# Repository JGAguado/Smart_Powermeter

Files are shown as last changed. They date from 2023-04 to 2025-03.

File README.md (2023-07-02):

[][documentation]
[][releases]
[](LICENSE)

[][maintenance]
[][buymecoffee]

# Smart Powermeter
The Smart Powermeter is powered by a ESP32-S2, allowing the measurement up to 6 CT clamps for reading electric current and real-time display on an 2.9" e-paper display.

<p float="left">
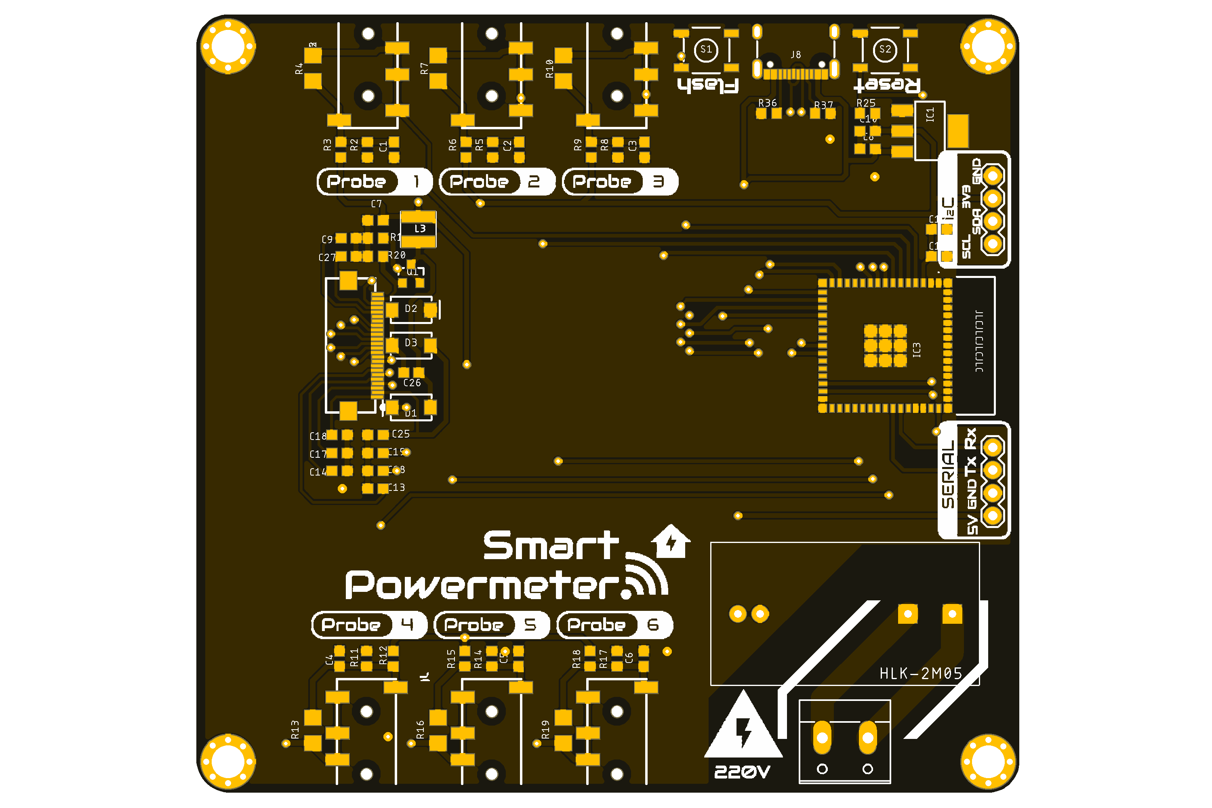
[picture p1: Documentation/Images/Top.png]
   
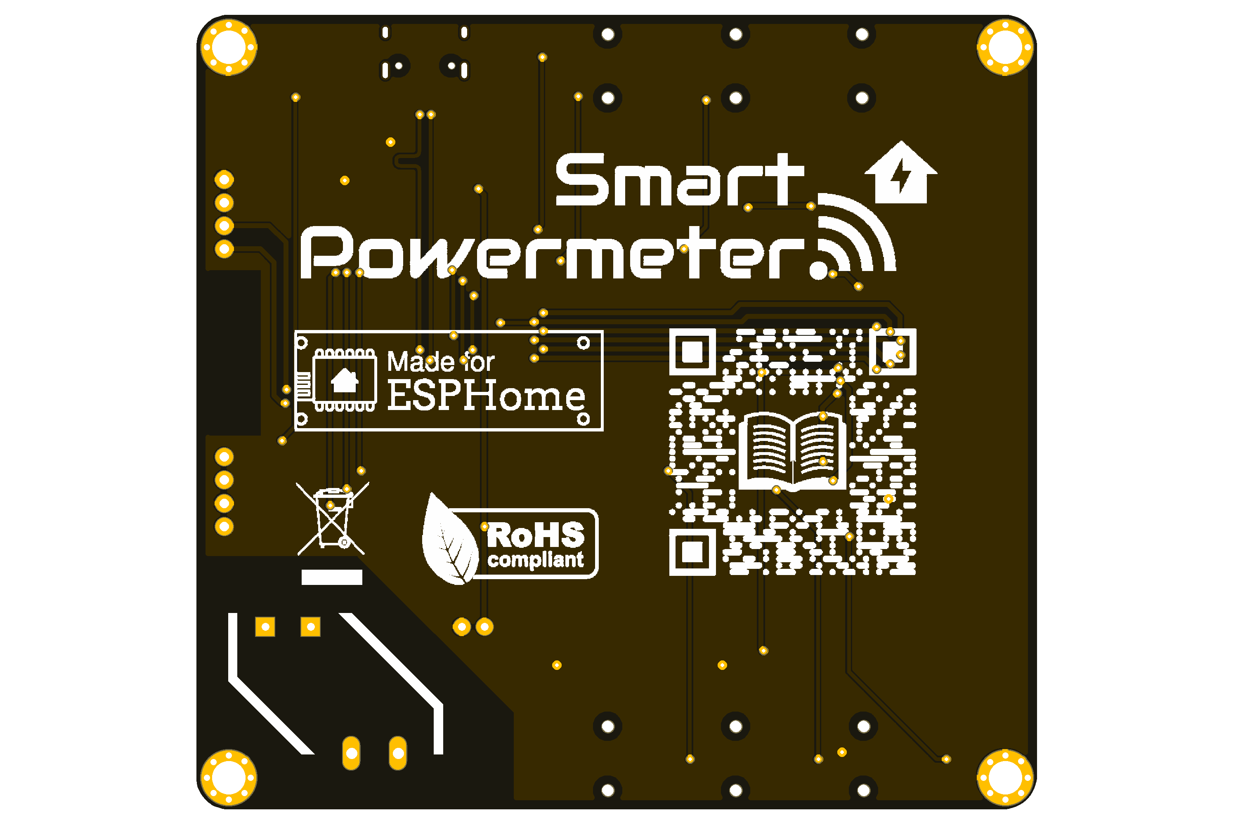
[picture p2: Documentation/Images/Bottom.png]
      
</p>

## Project tree

<li><a href="./Design/">Design</a></li>
<li><a href="./Documentation/">Documentation</a></li>

<li><a href="./README.md">README.md</a></li>

[documentation-shield]: https://readthedocs.org/projects/smart-powermeter/badge/?version=latest&style=for-the-badge
[documentation]: https://smart-powermeter.readthedocs.io/en/latest/

[releases-shield]: https://img.shields.io/github/release/JGAguado/Smart_Powermeter.svg?style=for-the-badge
[releases]: https://github.com/JGAguado/Smart_Powermeter/releases

[license-shield]: https://img.shields.io/badge/License-CC%20BY--NC--SA%204.0-lightgrey.svg?style=for-the-badge

[maintenance-shield]: https://img.shields.io/badge/maintainer-J.%20G.%20Aguado-blue.svg?style=for-the-badge
[maintenance]: https://github.com/JGAguado

[buymecoffee-shield]: https://img.shields.io/badge/buy%20me%20a%20coffee-support-yellow.svg?style=for-the-badge
[buymecoffee]: https://www.buymeacoffee.com/J.G.Aguado

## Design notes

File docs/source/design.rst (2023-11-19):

📐 Design
===========================

Electronic schematics
---------------------
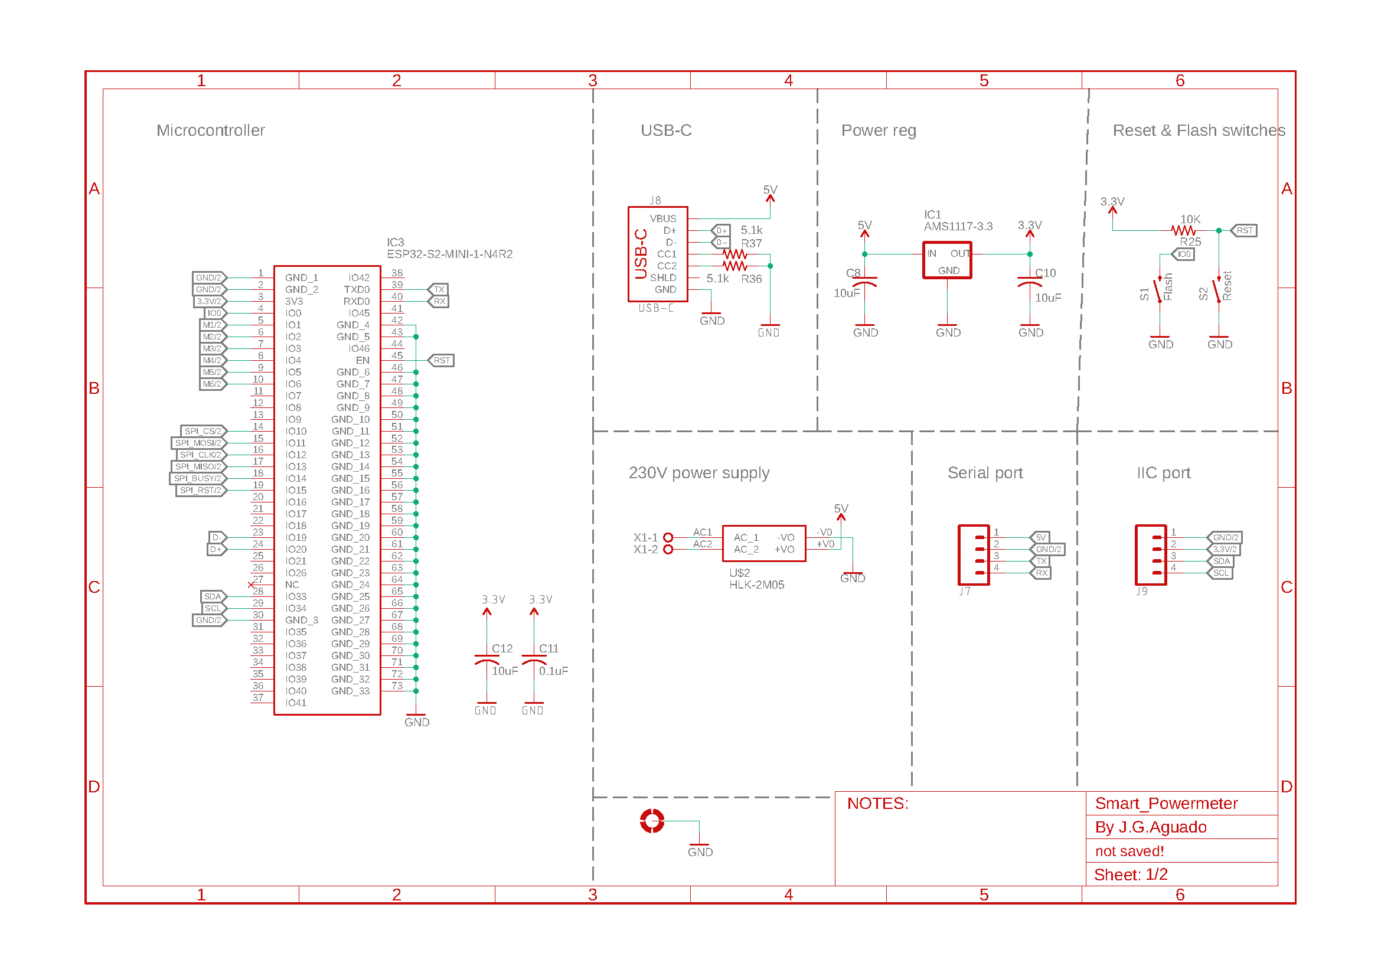
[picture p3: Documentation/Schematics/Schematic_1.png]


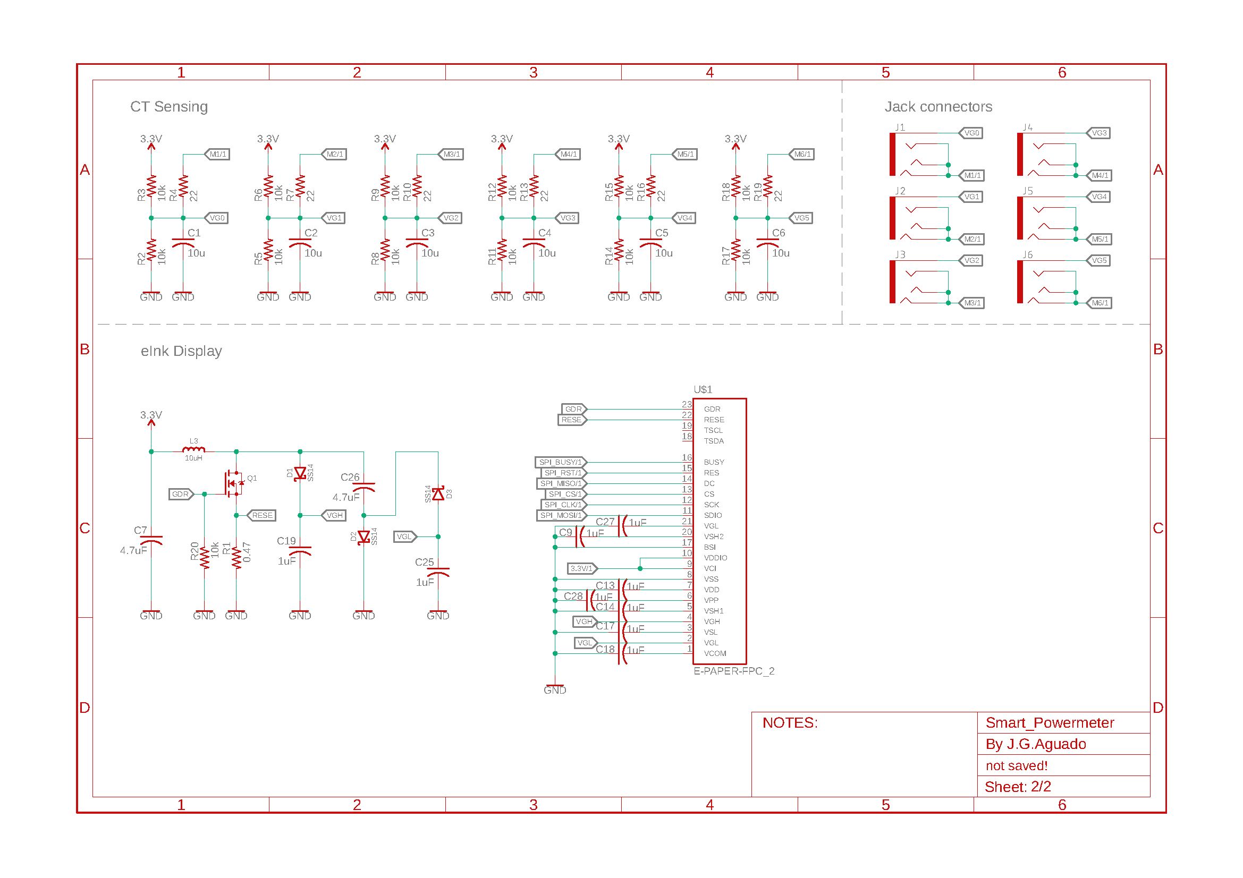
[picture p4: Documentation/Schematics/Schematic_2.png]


:download:`Download PDF <../../Documentation/Schematics/Schematic.pdf>`

.. _pcb:

:term:`PCB`
----------

.. raw:: html

    <iframe src="_static/ibom.html" height="800px" width="100%"></iframe>

Enclosure drawings
------------------

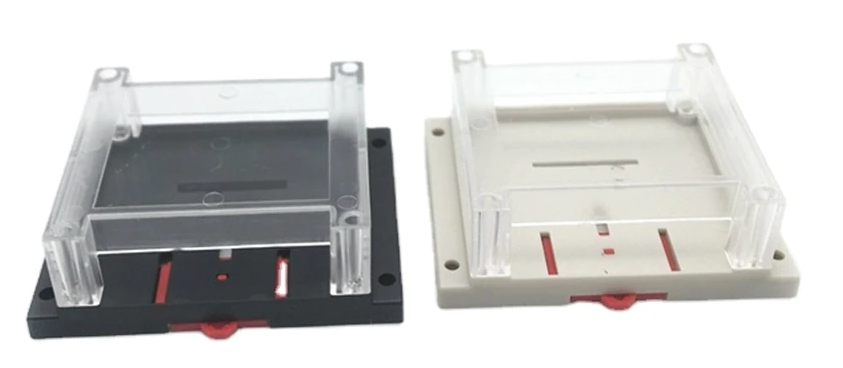
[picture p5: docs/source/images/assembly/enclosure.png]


:download:`Download PDF <../../Enclosure/LK-PLC01.pdf>`

Technical Specifications
------------------------

Microcontroller 
^^^^^^^^^^^^
.. list-table:: 
    :widths: 50 80
    :stub-columns: 1

    * - Module
      - ESP32-S2-MINI-1
    * - SoC
      - Xtensa® singlecore 32-bit LX7 up to 240MHz
    * - Flash
      - 4MB
    * - PSRAM
      - 2MB

Power
^^^^^^^^^^^^

.. list-table:: 
    :widths: 50 80
    :stub-columns: 1

    * - Input (AC) 
      - 100-240VAC | 50-60Hz
    * - Input (USB)
      - 5V @ 500mA

Features
^^^^^^^^^^^^

.. list-table:: 
    :widths: 50 80
    :stub-columns: 1

    * - Interface 
      - USB Type C 
    * - 
      - 2.4GHz WiFi 
    * - 
      - UART
    * - 
      - :term:`IIC` (:math:`I^2C`)
    * - Display
      - 2.9" e-paper 
    * - Sensors
      - 6x SCT-013-000 series CT-clamps

Dimensions
^^^^^^^^^^^^

.. list-table:: 
    :widths: 50 80
    :stub-columns: 1

    * - Size 
      - 92x87x20mm
    * - 
      - 115x90x40mm (with  enclosure)
    * - Weight
      - 60g
    * - 
      - 130g (with enclosure)

Environment
^^^^^^^^^^^^

.. list-table:: 
    :widths: 50 20 20 20 20 20
    :header-rows: 1
    :stub-columns: 1

    * - Parameter
      - Symbol
      - Min.
      - Typ.
      - Max.
      - Unit
    * - Working temperature [1]_
      - :math:`T_{amb}`
      - 0
      - 25 
      - 60
      - *°C*
    * - Storage temperature [1]_
      - :math:`T_{amb}`
      - 0
      - 25 
      - 60
      - *°C*

.. [1] Based on components datasheets.

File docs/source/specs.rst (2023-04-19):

Technical Specifications
========================

Electrical
----------

.. list-table:: 
    :widths: 50 20 20 20 20
    :header-rows: 1
    :stub-columns: 1

    * - Parameter
      - Symbol
      - Min.
      - Max.
      - Unit
    * - Supply voltage (AC)
      - :math:`V_{AC}`
      - 220
      - 240
      - *V*
    * - Power
      - *P*
      -  
      - 2
      - *W*

Environment
-----------

.. list-table:: 
    :widths: 50 20 20 20 20 20
    :header-rows: 1
    :stub-columns: 1

    * - Parameter
      - Symbol
      - Min.
      - Typ.
      - Max.
      - Unit
    * - Working temperature [1]_
      - :math:`T_{amb}`
      - 0
      - 25 
      - 60
      - *°C*
    * - Storage temperature [1]_
      - :math:`T_{amb}`
      - 0
      - 25 
      - 60
      - *°C*

.. [1] Based on components datasheets.

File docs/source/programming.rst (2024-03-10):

💻 Programming
===============

There are two main programming methods supported and tested with the |Product|: 

 * ESPHome
 * Arduino

In both scenarios, and if you are using the USB port or the Serial port for programming it, you
will first need to enter the board into flashing mode: press and hold the *Flash* pushbutton
while you reset the board (pressing once the *Reset* pushbutton).

.. Caution::
    When flashing the board, make sure its only powered by the USB/Serial port.
    
ESPHome
---------
`ESPHome <https://esphome.io>`_ is a well known platform for programming ESP-based devices 
with a very little effort. It is configured via YAML files and supports a wide range of functionalities
and sensors.

.. Important::
    For using ESPHome, and all its funcionalities, you need to have a `Home Assistant <https://www.home-assistant.io>`_ instance running
    in the same network as your |Product|.

The |Product| comes raw, without any firmware by default, therefore, you will need to flash it for first time. There are many ways to flash 
your ESPHome device (`locally <https://esphome.io/guides/getting_started_command_line.html>`_, `ESPHome Web <https://web.esphome.io>`_), but 
the one I strongly recommend is the one through the `ESPHome Add-on for Home Assistant <https://esphome.io/guides/getting_started_hassio.html>`_:

1. Make sure your ESPHome Add-on for HA is up to date and working. 
2. Add a new device, enter the name you want (like *Smart-Powermeter*), and skip the next step.
3. Select the *ESP32-S2* as the device type, skip the last step (installation). You will have created a provisional first configuration YAML file.

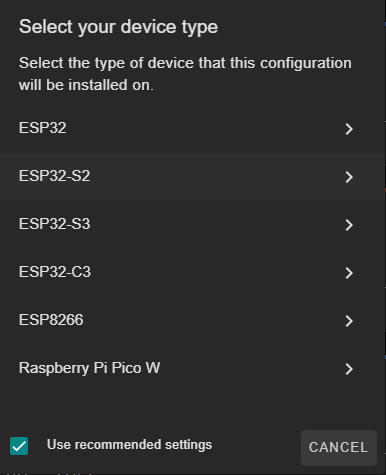
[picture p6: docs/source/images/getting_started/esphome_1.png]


4. Open the recently created file and replace the content with the example configuration. With all the dependencies, the working tree would look like:

.. Tip::
    A very easy way to upload and copy files (code or even images) into your ESPHome folder hosted in your HA instance is 
    with the help of the Visual Studio Code integration for HA. This way you can just drag and drop the files over the folder 
    on the Home Assistant’s Visual Studio Code navigation panel on your left.

| esphome
| ├── libraries
| │   └── icon-map.h
| ├── images
| │   └── Gauge.png
| │   └── Gauge_1.png
| └── smart-powermeter.yaml
| 
| 

In the folder structure above:
``icon-map.h`` 
    This *mapping* file is used to associate a variable name with the *icon ID* from the previous file. It contains the following code:
  
.. code-block:: C
   :linenos:

   #include <map>
   std::map<int, std::string> wifi_icon_map
   {
    {0, "\U0000f0b0"},
    {1, "\U0000ebe4"},
    {2, "\U0000ebd6"},
    {3, "\U0000ebe1"},
    {4, "\U0000e1d8"},
   };

``Gauge.png`` and ``Gauge.png``
    This are some customized gauges to be plotted as part of the background.

    
    

``smart-powermeter.yaml``
    This is the YAML configuration file, the most important file that configures your ESPHome-based |Porduct|:

.. Note:: You might need to keep the encription keys *OTA* and *API*

.. literalinclude:: files/configuration.yaml
   :language: yaml
   :linenos:

5. Click on install, make sure that the the board is connected via the USB-C (and that it is into flashing mode, see up in this guide) to the device running the Home Assistant (in my case a Raspberry Pi) before selecting the mode of installation.

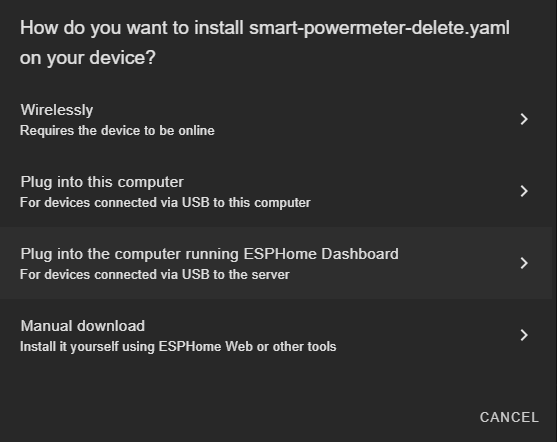
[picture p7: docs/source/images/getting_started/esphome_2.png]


6. Select the Serial port and let it run, it might take some minutes. 
7. Once it's done, you will have to exit the flashing mode: press the *Reset* pushbutton once. 

Now, your ESPHome-based |Product| should be ready to log data and stream it to your Home Assistant. Note that the current configuration is just an example and you can customize it at your will, including the calibration. 

Flash Tools
^^^^^^^^^^^^
If you want to deploy an ESPHome already compiled *.bin* image, you can use Espressif's official `Flash Download Tools <https://www.espressif.com/en/support/download/other-tools>`_ to upload it into your Smart Powermeter. 
As an example (and test) you can use this :download:`smart-powermeter-offline.bin <files/smart-powermeter-offline.bin>` image with the address `0x0`, make sure `DoNotChgBin` is checked:

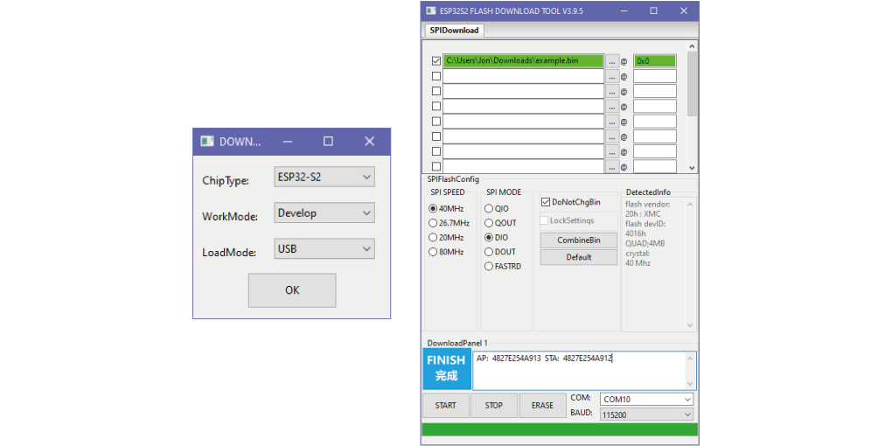
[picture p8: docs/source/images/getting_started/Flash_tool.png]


Arduino
--------
If you are still interested in programming directly with the Arduino IDE, the procedure is no 
different than with any other ESP32 devices:

1. Open the Arduino IDE and go to File -> Preferences option.
2. Add to the *Additional Boards Manager URSLs* the url:

.. parsed-literal::

    https://dl.espressif.com/dl/package_esp32_index.json

3. Close the preferences and open in the menu Tools -> Board -> Boards Manager.
4. Search for *esp32* and install it. This might take some time.
5. Now you can select the board *ESP32S2 Dev Module* as the target board. Leave the rest of parameters 
   by default.
6. Select the correct port and remember to enter the board into flashing mode before uploading the sketch.

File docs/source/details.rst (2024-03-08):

💡 Details
===============

Power
--------
The |Product| can be powered in two ways: through the USB-C (only for programming and testing purposes) **or** through the AC Input, but not simultaneously. 

AC Power
^^^^^^^^^^^^^
The `HLK-2M05 <https://www.hlktech.com/en/Goods-39.html>`_ module is a 2W AC-DC step-down 
switching power supply module, ready to receive 100-220V AC and deliver 5V DC that later on is reduced to 3.3V through an LDO (for the ESP32 module).

The board is designed to be powered directly through the screw terminal block. Before plugging the wires in, make sure they have no power.

Input
-----------
The |Product| supports up to 6 independent *analog inputs* ready to read CT clamps (or probes):

.. _pinout:

.. list-table:: Pinout table
    :widths: 10 20
    :header-rows: 1

    * - GPIO
      - Name
    * - 01
      - Probe 0
    * - 02
      - Probe 1
    * - 03
      - Probe 2
    * - 04
      - Probe 3
    * - 05
      - Probe 4
    * - 06
      - Probe 5

Regarding the kind of CT-clamps, I recommend the SCT-013 series, comming in a wide number of ranges and with a 3.5 jack connector:

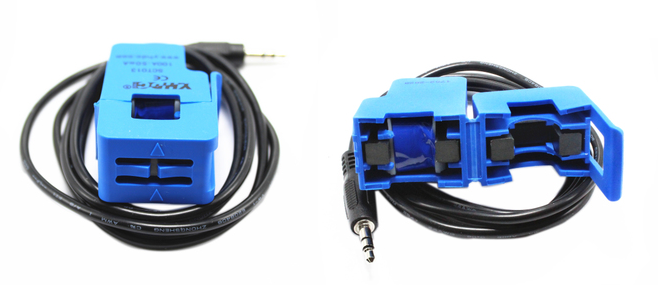
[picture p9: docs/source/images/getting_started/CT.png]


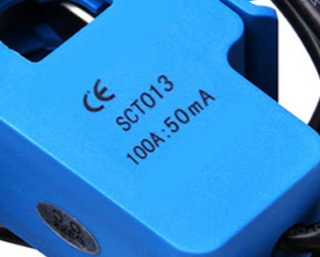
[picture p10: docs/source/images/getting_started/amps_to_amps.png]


.. list-table:: 
    :widths: 50 50
    :header-rows: 1

    * - Model
      - Ratio
    * - SCT-013-000
      - 100A:50mA
    * - SCT-013-005
      - 5A:1V
    * - SCT-013-010
      - 10A:1V
    * - SCT-013-015
      - 15A:1V
    * - SCT-013-020
      - 20A:1V
    * - SCT-013-025
      - 25A:1V
    * - SCT-013-030
      - 30A:1V
    * - SCT-013-050
      - 50A:1V
    * - SCT-013-060
      - 6A:1V
    * - SCT-013-000V
      - 100A:1V

When selecting a CT clamp, it is crucial to consider the anticipated measurement range. This ensures accurate measurements and prevents 
exceeding the ESP32's maximum reading range.

.. Note:: 
  The default CT clamp in the set is the SCT-013-000, which has the highest range in the series. However, for measurements al low power <10W, it may not provide the desired level of quality.

Each channel incorporates a simple internal circuit that adjusts the induced voltage from the CT clamp (proportional to the measured current) 
to prepare the signal for reading by the :term:`ADC` of the microcontroller. For more details on the circuit, refer to this 
`guide <https://docs.openenergymonitor.org/electricity-monitoring/ct-sensors/interface-with-arduino.html>`_.

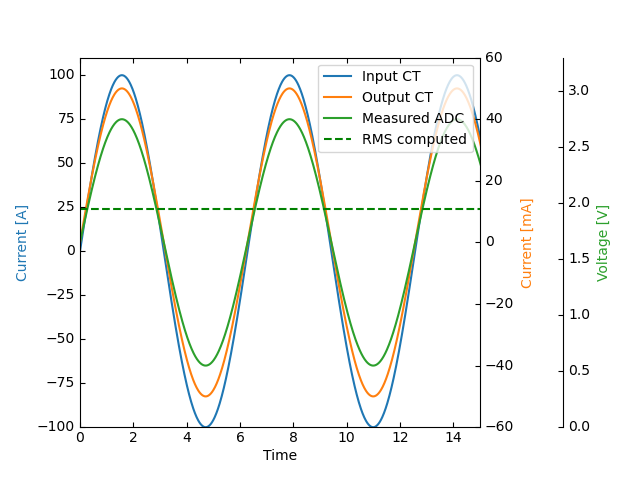
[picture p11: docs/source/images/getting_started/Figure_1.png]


In general, except for the SCT-013-000, the induced voltage can be read by the conditioning circuit mentioned earlier. 
However, if the CT clamp output is also a current, a burden resistor is necessary. The |Product| includes a **22 Ohm** resistor for 
convenience, making it easier to desolder if not needed, as explained in the :ref:`desoldering` section.

E-paper
--------
    
The |Product| offers support for a 2.9" black and white e-ink display, through a clamp connector. The pinout with respect to the ESP32 GPIOs goes as follows:

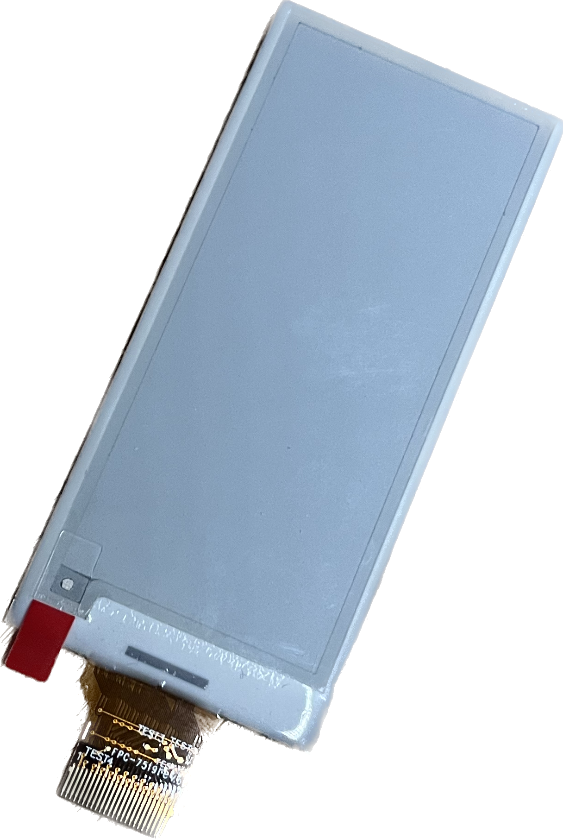
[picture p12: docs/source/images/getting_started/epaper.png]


.. list-table:: Pinout table
    :widths: 10 10 
    :header-rows: 1

    * - ESP32
      - E-paper
    * - 14
      - BUSY
    * - 15
      - RST
    * - 13
      - DC/MISO
    * - 12
      - CLK
    * - 11
      - MOSI
    * - 10
      - CS

Communications
-----------
In addition to the analog input mentioned before, there is also a direct connection to:

:term:`IIC` (:math:`I^2C`) bus:
^^^^^^^^
This port is not accessible from external pins, but internally connected to a BMP280 sensor that can offer info about 
environmental temperature & pressure:

:SDA: *GPIO33*
:SCL: *GPIO34*

Serial bus:
^^^^^^^^^^^
:Tx: *TXD0*
:Rx: *RXD0*

.. _enclosure:

Enclosure
---------
The |Product| has been designed to fit in the electronics enclosure LK-PLC01,
compatible with DIN rails and screws, and it is recommended for indoors only.



:External size: 115x90x40mm
:Material: ABS Plastic
:Color: Transparent cover, black or beige base

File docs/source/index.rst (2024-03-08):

Smart Powermeter
###############

.. raw:: html
        
    <iframe src="_static/carousel.html" style="width: 100%; height: 300px; border: none;"></iframe>

Welcome to the documentation page of the |Product|, an electronic board based on the ESP32 with 
the target of monitoring the real-time consumption of AC sources.

It can be powered from a :math:`220 V_{AC}` source so it can be mounted on the electric cabinet in order to monitor your home electric consumption.

In addition it can support 2.9" black and white e-paper display, in order to 
provide graphic information about the measured consumption, as well as spent money or any info you want to show.

Contents
--------

:doc:`safety`
    How to operate and manipulate the |Product|.

:doc:`details`
    A deeper explanation on the systems of the |Product|.

:doc:`getting_started`
    First steps for configuring and working with the |Product|.

:doc:`design`
    Design files of the |Product|.

.. _support:

Technical support
-----------------

If you have technical problems or cannot find the information that you need in the provided documentation, 
please contact me directly:

:Author: |Author|
:Contact: |Email|

:Board: |Product|
:Revision: |Release|
:Date: |Date|

.. toctree::
   :maxdepth: 3
   :hidden:

   safety   
   details
   getting_started
   design   
   glossary
   faq

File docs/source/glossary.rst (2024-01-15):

📚 Acronyms
============

.. glossary:: 
   :sorted:

   IC
       Integrated Circuit

   ADC
        Analog-to-digital converter

   TTL
       Transistor-Transistor Logic

   I/O
       Inputs / Outputs

   GND
       Ground

   OTA
       Over-the-Air

   PCB
       Printed Circuit Board

   PWM
       Pulse-width Modulation

   FF
       Flip Flop

   FAQ
       Frequently Answered Questions

   FPC
       Flexible Printed Circuit

   LDR
       Light Dependant Resistor

   LED
       Light Emitting Diode

   RGBW
       Red-Green-Blue-White

   NTC
       Negative Temperature Coefficient

   MDI
       Material Design Icons

   BOM
       Bill of Materials

   ESD
       Electrostatic Discharge

   SMD
       Surface-mounted device

   SMT
       Surface-mount Technology

   THT
       Through Hole Technology

   IIC
       Inter-Integrated Circuit

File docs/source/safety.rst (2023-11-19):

🦺 Safety guidelines
=================

These safety guidelines, the operation instructions and the limit values listed in :doc:`specs` are to be read carefully before operating the product.

.. Caution::
    This product has been designed for being used in domotic applications. 
    It was not designed for any use involving serious risks or hazards that could lead to death, injury, serious physical damage, or loss of any kind without the implementation of exceptionally stringent safety precautions.

Risk of electric shock
----------------------

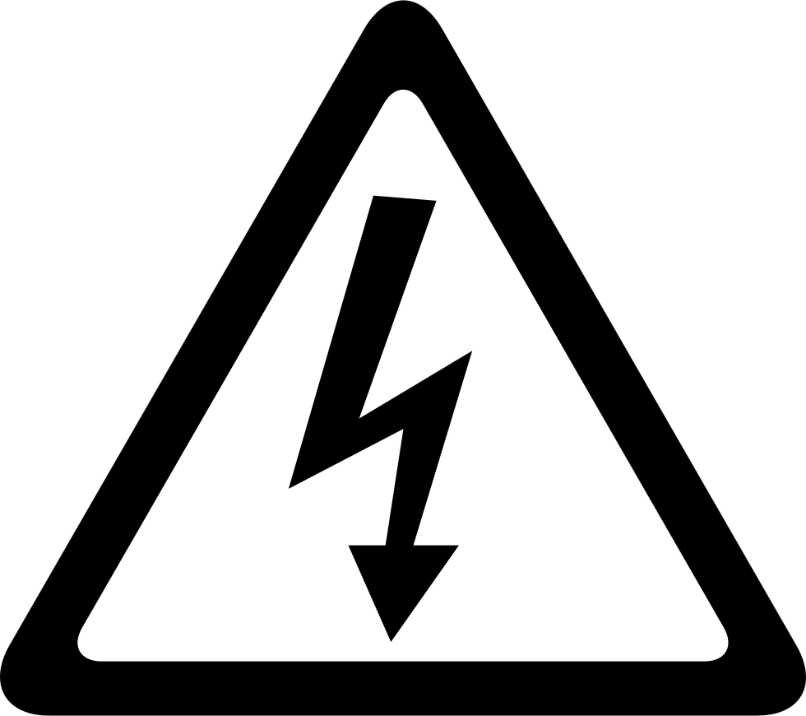
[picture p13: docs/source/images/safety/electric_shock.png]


The usage of this product could imply working with high voltage installations (:math:`220-240 V_{AC}`). Perform any action, specially in the area with this symbol on the board, with the appropriate means and always with safety. 

If you have any question, please check with technical support (:ref:`support`) before taking any action potentially dangerous.

Protection against :term:`ESD`
------------------------------

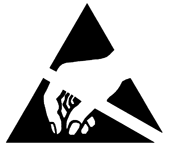
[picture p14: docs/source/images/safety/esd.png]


The |Product| contains components sensitive to :term:`ESD`, which can be damaged by inappropriate handling. 
It's therefore necessary to provide some safety precautions against :term:`ESD` during the handling and operation.

Usage, transport and storage
----------------------------

During the use, transport and storage, this product must be protected from any mechanical stress 
(forces applied over the board or it's components), temperatures out of the data-sheet's range, high 
environmental humidity or aggressive atmospheres.

Avoid using it in areas where it cannot be assured the previously mentioned environmental conditions.

Repairs
-------

If any of the components on the board gets damaged, a reparation is possible. This repair can be performed by 
yourself if you identify the problem and have the means for desoldering & soldering. If this is not the case,
just write to the :ref:`support` mail to reach a solution.

Disposal
--------

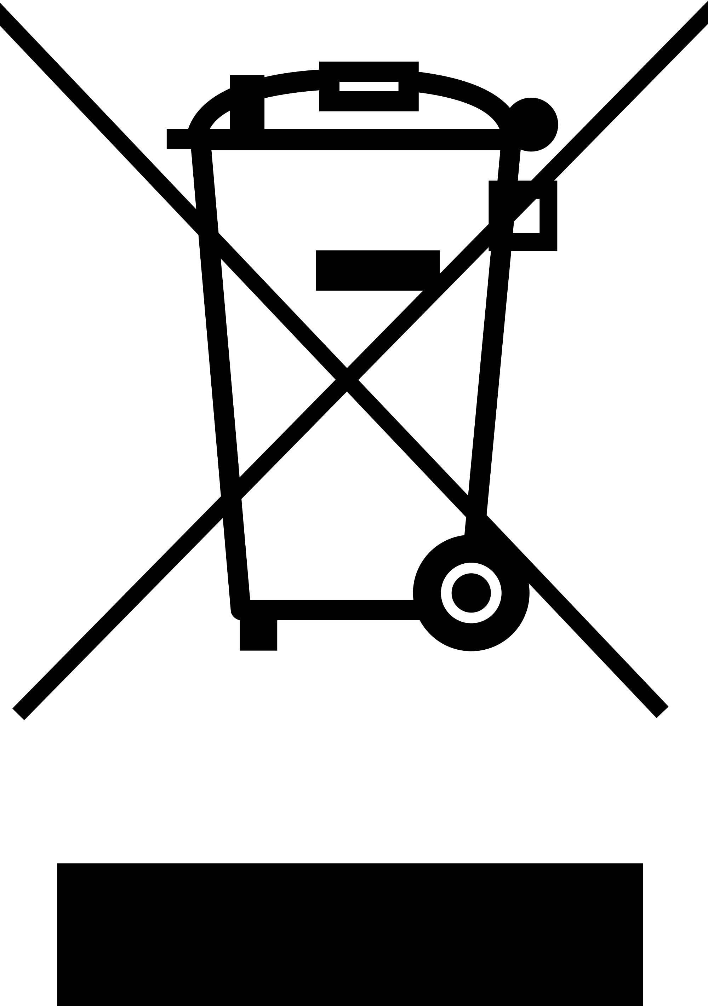
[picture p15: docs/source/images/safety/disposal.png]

    
In accordance with national and local environmental protection and material recovery and recycling regulations, 
electronic devices that can no longer be used (in case a repair is not possible) must be disposed of separately 
and not with normal household garbage.

Restriction of Hazardous Substances
-----------------------------------

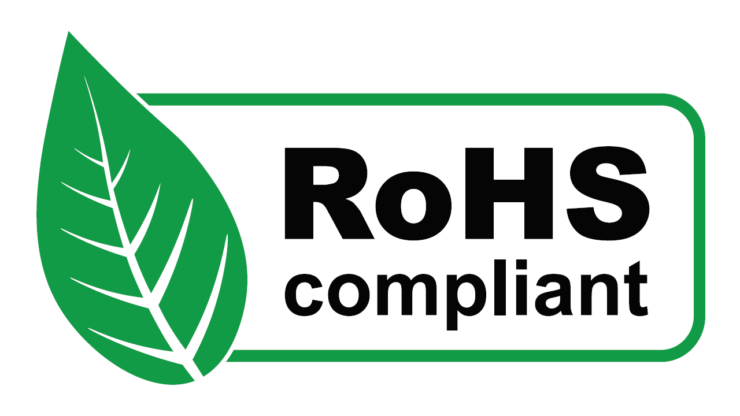
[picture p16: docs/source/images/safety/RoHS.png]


The :term:`PCB` and the electronic components mounted on the |Product| have been manufactured attending to the EU rules 
restricting the use of hazardous substances (RoHS) in electrical and electronic equipment to protect the 
environment and public health.

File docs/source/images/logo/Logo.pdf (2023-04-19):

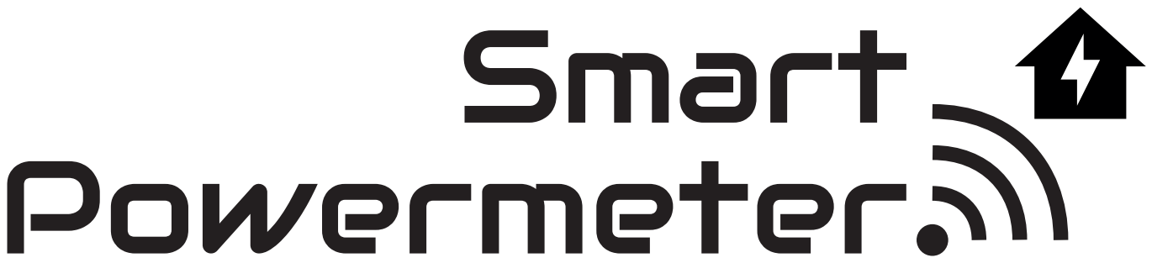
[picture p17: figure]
Smart Powermeter

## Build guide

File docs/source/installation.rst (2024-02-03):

🛠️ Installation
===============

Deployment
-----------

.. Danger::
    The installation of the Smart Powermeter should only be carried by people with **good knowledge about high-voltage electric installations** 
    and familiarized with the procedure that involves installing ct-clamps around main voltages.

After the board has been programmed physically, at least once, it should be ready to receive further updates :term:`OTA`. This means that 
the |Product| can be deployed and installed on it's final place, like an electric cabinet:

1. Locate an empty space on the DIN rail where you can install the enclosed |Product| and mount it.
2. Plug the CT-clamps into the |Product| through the jack connectors. 

.. Important::
    Don't introduce the jack connector completelly, leave ~1 millimeter, otherwise you might not see any signal.

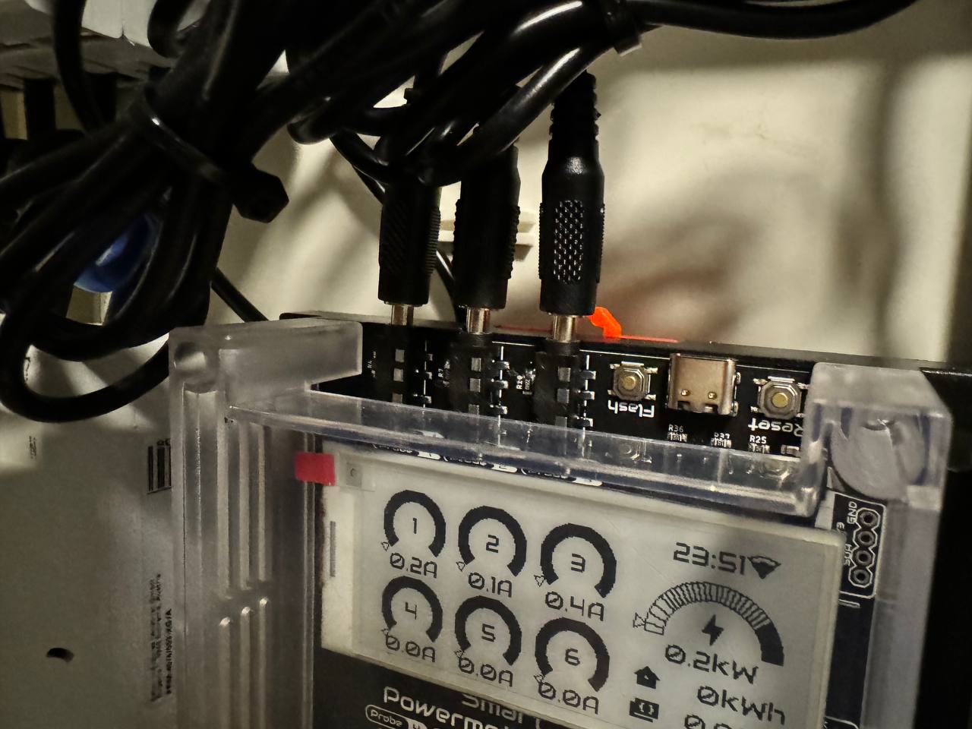
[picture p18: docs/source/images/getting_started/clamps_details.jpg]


3. Open the CT-clamps and close them around the power line you want to measure.

.. Caution:: 
  High-voltage cables are very rigid and using too much force for helping claping the instrument 
  around the cables may disconnect them.  

4. Power the |Product| out of any surrounding power lines. **Before connecting anything make sure it is not powered**.

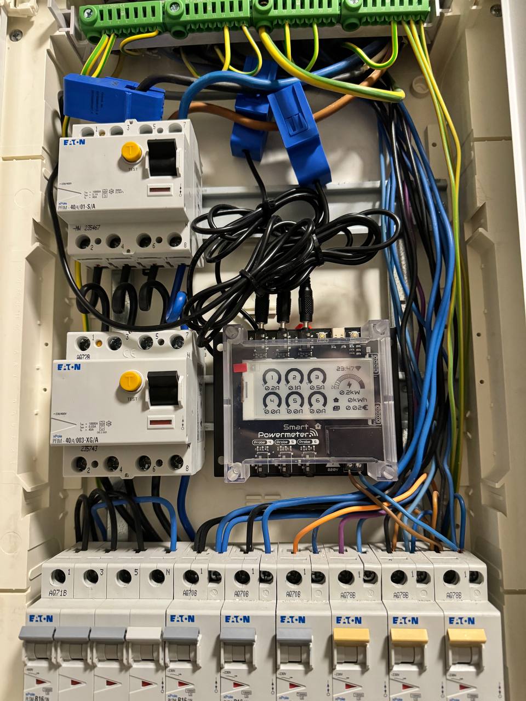
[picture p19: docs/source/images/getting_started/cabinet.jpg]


Calibration
------------

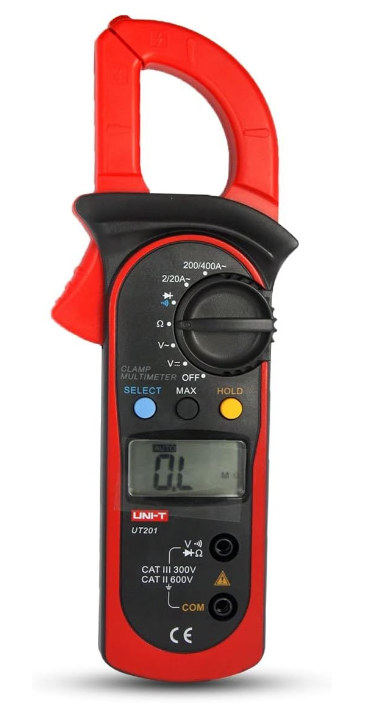
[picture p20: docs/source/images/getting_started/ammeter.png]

    
Although the theoretical value calculated should be good enough for the measurements, I strongly recommend to calibrate each channel with an external handheld ammeter:

In general lines, calibration procedure consists on the basic points:

1. Instrument with an external ammeter the same power line you are measuring with your CT-clamp.
2. Measure at multiple currents, for that turn on different loads consumming differently.

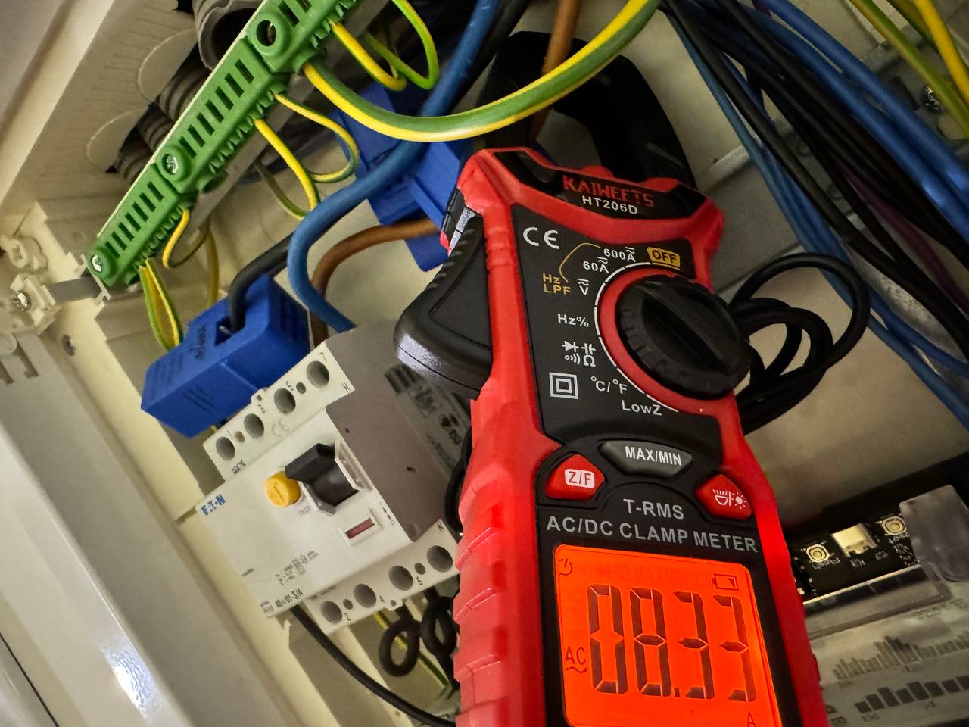
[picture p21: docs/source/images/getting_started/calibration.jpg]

    
3. Apply the coefficients. On ESPHome this is done by entering the multiple measurement points into a filter *calibrate_linear*, like this:

.. parsed-literal::

    filters:
      - calibrate_linear:
          - 0 -> 0
          - 0.042 -> 2.72 # Where 0.042 was the reading from the ESPHome and 2.72 the amps measured with the calibrated instrument

4. Verify that the calibrated measurement matches with what the ammeter displays. Test different loads again.

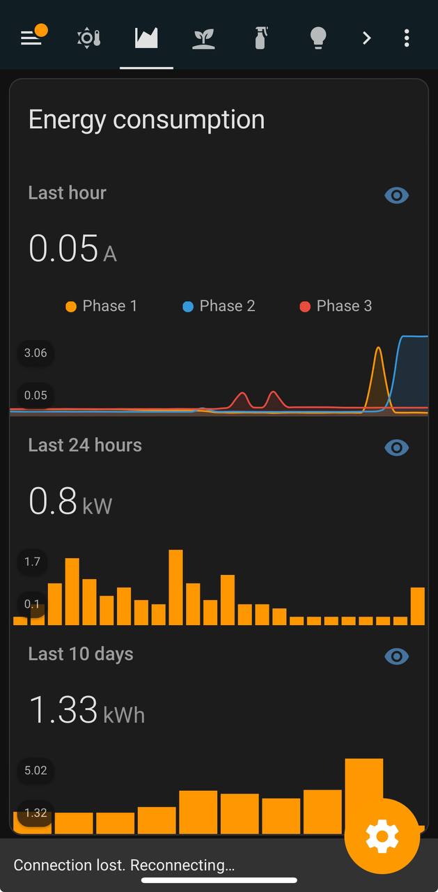
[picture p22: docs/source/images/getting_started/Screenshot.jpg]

    
    HA App screencapture of testing loads on the different phases.

Home Assistant setup
--------------------

After the device is installed and calibrated, make sure you add the computed power parameter as part of the grid consumption.

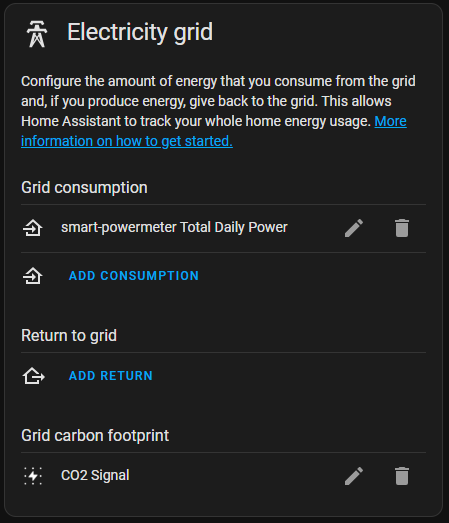
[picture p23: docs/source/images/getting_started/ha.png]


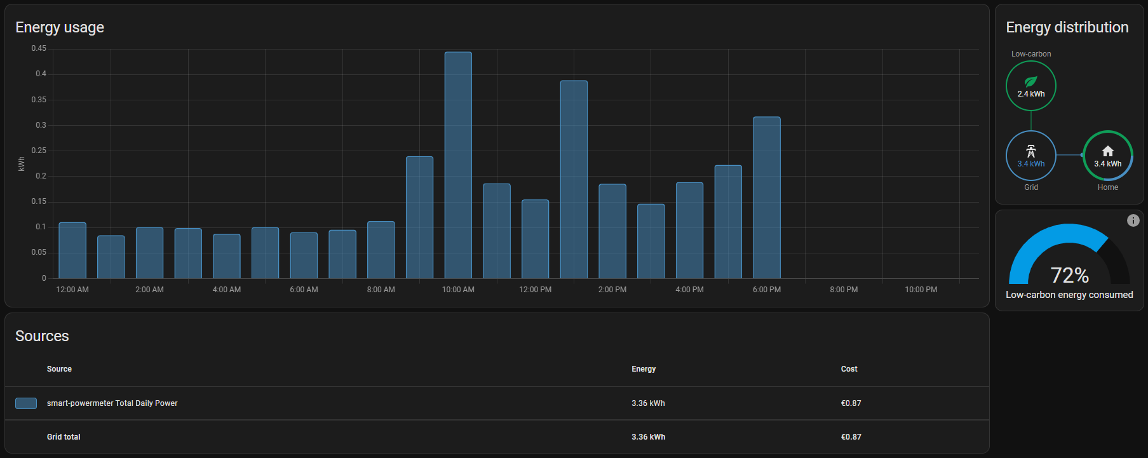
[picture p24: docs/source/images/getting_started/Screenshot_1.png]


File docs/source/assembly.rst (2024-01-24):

🏗️ Assembly
============================

Soldering 
----------
.. Important::
    Please note that some components in this board need to be soldered.

The |Product| comes as a set consisting on a :term:`SMD` pre-soldered board to which you will need to mount the following components:

* `HLK-2M05 <https://www.hlktech.com/en/Goods-39.html>`_ power module, a 2W AC-DC step-down switching power supply module :term:`THT` solderable.
* A 2-Pin 2mm-pitch screw terminal block, for the AC power imput, also :term:`THT` solderable.

.. Note:: 
  When buying the |Product| read the product description to make sure these two components are included, otherwise you might need to get them on your
  own.

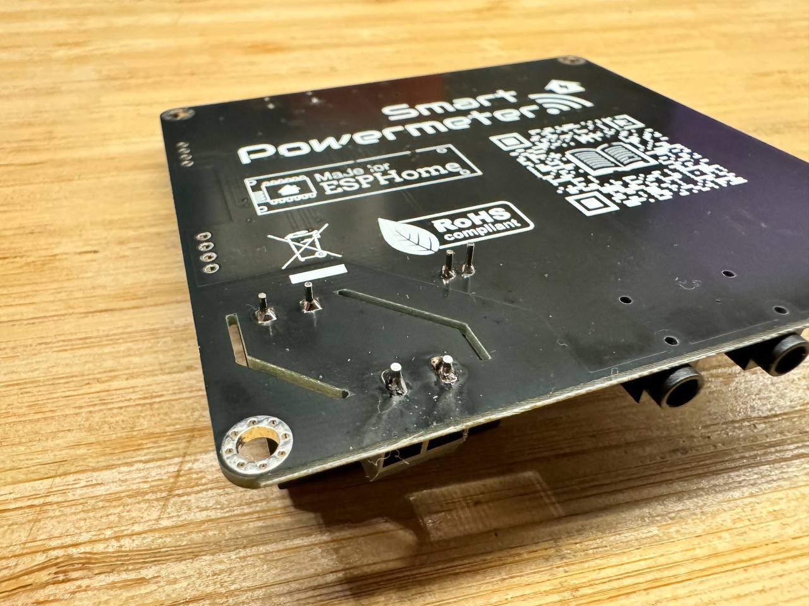
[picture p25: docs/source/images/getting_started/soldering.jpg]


The soldering of these two components is quite fast, just make sure not to bend any of the power supply module pins. If you have never soldered or you want to improve your soldering techniques I recommend you 
the `Adafruit Guide To Excellent Soldering <https://learn.adafruit.com/adafruit-guide-excellent-soldering>`_

.. _desoldering:

Desoldering
------------
If you ever need to desolder any burdern resistor, for instance, when opting for a different CT clamp on that channel, simply apply heat and remove it carefully.

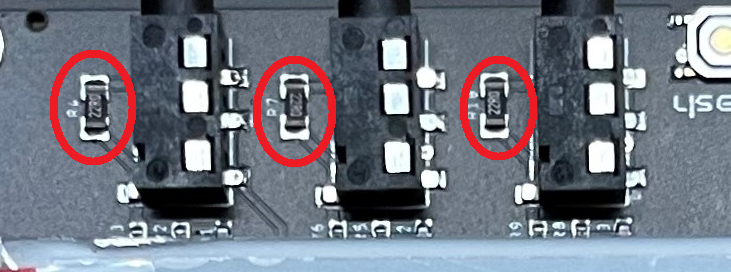
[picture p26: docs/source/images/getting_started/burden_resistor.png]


Assembly
--------
Once the board is fully soldered, it's time to mount the e-paper display (in case you are using this accessory to display real-time information):

1. Open the clamp connector, by smoothly pulling up the tab.
2. Introduce the e-paper :term:`FPC` with the exposed pads facing down (against the PCB)
3. Close the clamp connector
4. Bend carefully the e-paper's :term:`FPC` in a way that the panel rests over the PCB. Add a very small piece of double-side tape on the rear to fix it.

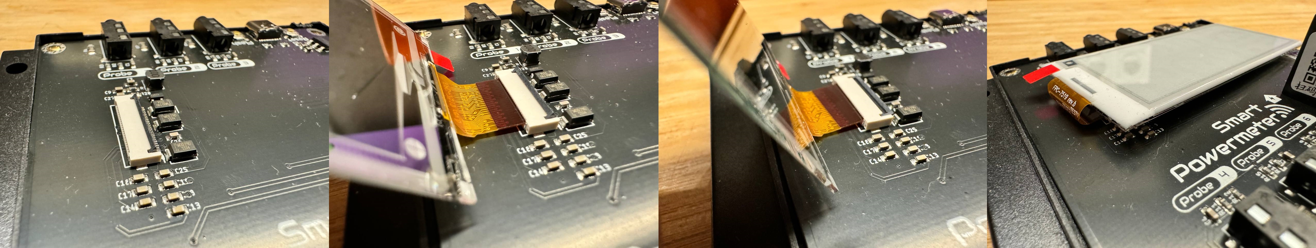
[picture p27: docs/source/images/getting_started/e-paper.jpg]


Last but not least, it is highly recommended to mount the |Product| on an enclosure (like the suggested :ref:`enclosure`) to prevent unintended contacts between the bottom 
side of the board (since the hig-voltage pins are exposed).

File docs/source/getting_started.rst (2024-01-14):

🚀 Getting started
===============
  
    Trust me, I know what I'm doing...

    -- Every engineer while ignoring the instructions book.

Regardless of your professional background, I encourage you to have a quick read through the following pages in order to get your |Product| 
onboarding smoother and minimize the risk of damaging the device and/or yourself.

.. toctree::
   :maxdepth: 2

   assembly
   programming
   installation

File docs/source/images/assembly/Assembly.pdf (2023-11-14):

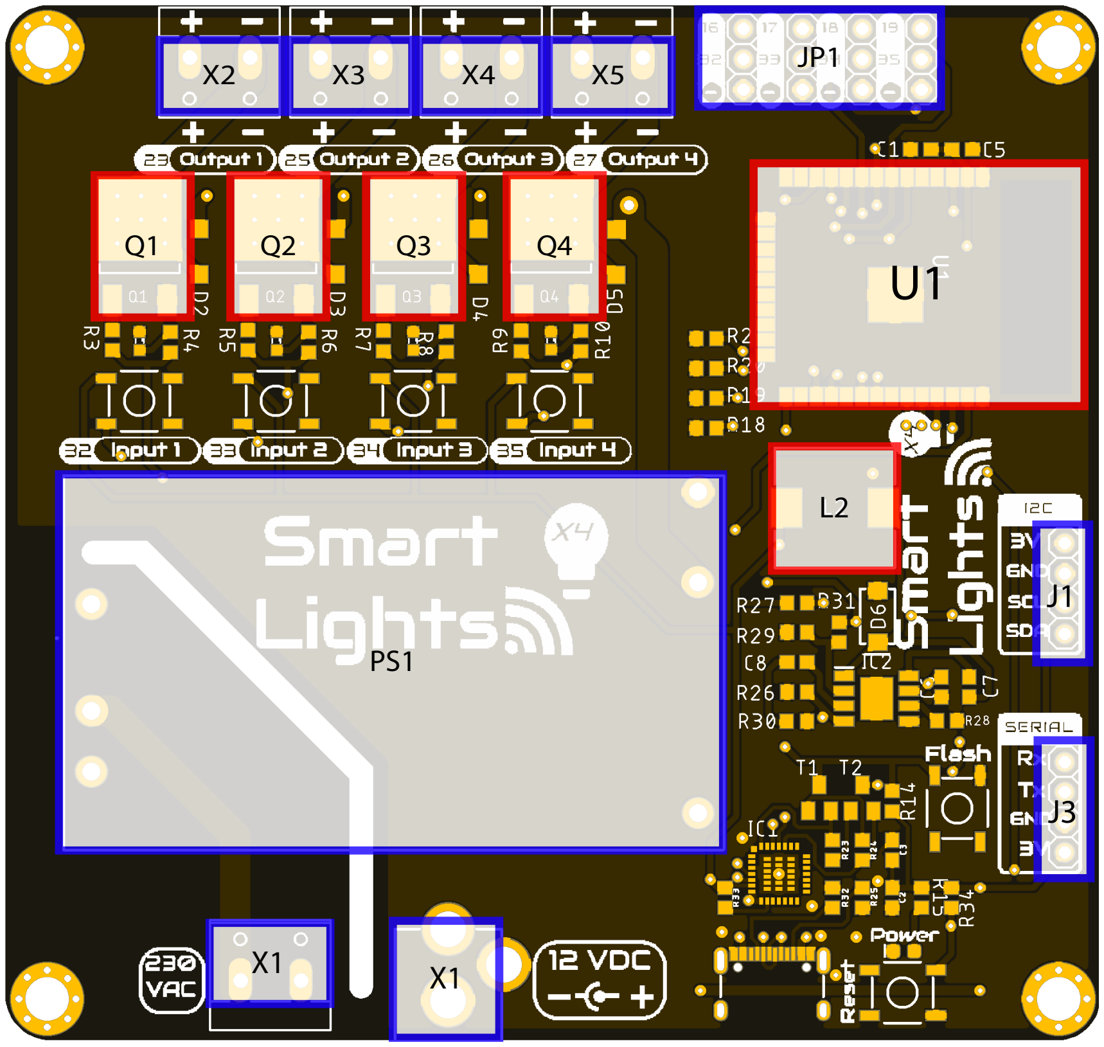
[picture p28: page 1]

Q1
U1
Q2 | Q3 | Q4

X2

X1 | X1

J1

J3

JP1

PS1

X3 | X4 | X5

L2

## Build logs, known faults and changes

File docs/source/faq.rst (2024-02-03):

💬 :term:`FAQ`
=============================

The readings from the CT clamps are very noisy and I don't see any signal at all
    Most likely is because the jack connectors from the CT clamp are too deeply inserted: try pulling them out about ~1-2 mm from the point where they would bottom out.  

Can I upload ESPHome directly from the Home Assistance setup running on my Raspberry Pi?
    Yes you can, and actually this is one of the simplest and more effective way to upload ESPHome.

Can I upload firmware through the USB-C?
    Yes, the ESP32-S2 includes a full-speed USB On-The-Go (OTG) interface to enable USB communication.

Can I upload firmware through the Serial bus?
    Yes you can, however this is only recommended if you have troubles using the USB port and you are familiar with the procedure.

I have CT clamps that gives me the output in voltage instead of current (100A:1V), is it still compatible?
    Yes, you just have to desolder the burden resistor close to the connector of the channel you want to use. 

Am I obtaining the accurate measure of power consumption?
    Strictly speaking, no; what you're obtaining is the **apparent** power. The real or true power of a circuit considers the phase (power factor). 
    As we are solely monitoring the current and assuming a constant voltage, we cannot factor in the phase shift between voltage and current. 
    Consequently, what we can calculate is the apparent power. Nevertheless, unless you have robust inductive loads at home, such as powerful motors, 
    the power factor tends to be close to unity, resulting in a very close alignment between the measurement of apparent power and real power.
    If you want to understand more about the differences between True, Apparent and Reactive power have a look at this `article <https://www.allaboutcircuits.com/textbook/alternating-current/chpt-11/true-reactive-and-apparent-power/>`_ 

I want to use the :term:`IIC` port for expanding the possibilities, how can I do it?
    Once you have located the sensor that you want to connect to the :term:`IIC` port, check that is compatible with the 3.3V power supply from the |Product|. 
    If this is the case, just connect it directly, power the board and update the firmware!

When I try to compile the given YAML and upload it into the board I get some error messages saying that I miss some files (Audiowide.ttf, icon-map.h, etc). How to fix it?
    Just the configuration YAML file isn’t enough and you might get an error asking for missing items (the fonts and the images). The reason is because
    on the configuration we are asking for some files (the fonts that you want for the digits or the icons and the background image with the gauge, for example).
    
    Therefore you need to upload into the folder with the configuration YAML file the required files. I strongly suggest to use Visual studio code and just drag and 
    drop the items according to the structure mentioned on the :ref:`esphome` programming section.

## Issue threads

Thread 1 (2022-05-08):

Power transformer on the left

JGAguado, 2022-05-08:
So it doesn't block the USB-C port

JGAguado, 2023-07-05:
c3e27f7b080b054ba54b7329635745d98501c130

Closed 2023-07-05.

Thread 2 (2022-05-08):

Silkscreen bug

JGAguado, 2022-05-08:
Start in Input_0 and missing input_4

JGAguado, 2023-07-05:
c3e27f7b080b054ba54b7329635745d98501c130

Closed 2023-07-05.

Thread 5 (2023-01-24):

ESP32-S module based

JGAguado, 2023-01-24:
- Board design based on the smart-lights /smart-garden platforms
- E-ink based (2.9 inches)

JGAguado, 2023-07-05:
c3e27f7b080b054ba54b7329635745d98501c130

Closed 2023-07-05.

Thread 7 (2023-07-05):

Production files

CountParadox, 2023-07-05:
Hi OP

Thanks for the hard work, your board looks amazing :)

Would it be possible to get some production files eg. gerbers, drill, bom, placement etc to get some board s manufactured at JLCPCB or PCBway for example ?

Your store is out of stock and theres no clues when they may be back :(

Myself and a few friends would love to get a few boards

I would appreciate any help !

Thank you

JGAguado, 2023-07-05:
Hi Lewis,

Thanks for your interest and support! Normally I don't upload the production files, but the design ones, so you can freely generate your production file.

Since I am still testing the V2R1, I haven't tagged a release, I hope to validate the functionalities this next week and update the documentation, but the design files already available wouldn't change.

If you are more interested in acquiring some semi-assembled units (I have some prototypes V1R1 and V1R2), send me an email to jon-garcia@hotmail.com

Closed 2023-07-05.

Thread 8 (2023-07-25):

No voltage measurement

agkaminski, 2023-07-25:
Please take a note that you cannot accurately measure AC power by only measuring current. Without information about phase shift between the voltage and the current you cannot measure real power usage - you can only measure apparent power, which is kinda useless.

Wikipedia has it laid out accurately enough: https://en.wikipedia.org/wiki/AC_power

JGAguado, 2023-07-25:
The current board provides a real-time **estimation**. Voltage measurement is a feature that will come in future versions.

agkaminski, 2023-07-25:
You seem to misunderstand the issue - amplitude of the voltage is not really needed (as we can assume 230V and live with it), but the phase is necessary

JGAguado, 2023-07-25:
Dear Aleksander, I understand perfectly the issue. If you dig a little bit into the firmware my board is compatible with (ESPHome), you will find that the power factor computation is not supported a the moment. Since I don't take part in the firmware development, it made no sense for me to implement (at least in the first versions) the voltage measurement for computing the phase offset, true and reactive power.

Saentist, 2025-03-31:
@JGAguado
Voltage can be taken from Home assistant
https://esphome.io/components/sensor/homeassistant.html

That's how, if any device report it already can be used.
Documentation and config file update needed also.

Closed 2023-07-25.

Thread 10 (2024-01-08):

BOM and CPL Files Available?

mdframe, 2024-01-08:
Does anyone have all the files necessary to order the PCB from JLCPCB for board and components for R2?

Thank you,

Matt

mdframe, 2024-01-08:
Is there any way to get notified when the next batch is ready for an order?  I appreciate the quick response and yes all I am looking to do is place an order.

Thank you,

Matt

JGAguado, 2024-01-08:
Let me come back to you on this channel when it becomes available.

JGAguado, 2024-01-09:
Dear @mdframe,

You are very welcome! Would be great to have you supporting the Smart Powermeter's features on ESPHome! And yes, please keep me posted on any updates you make!

At the moment, the published code, is focused on the measurement, and a "Hello World" test for the display. So if you would make any advance with some cool graphs or so, please keep me posted 😃 !!

The problem with the code running behind the Smart Powermeter shown in the photos, is that it required a Python script running in Home Assistant to convert the gathered power data from ESPHome into a scaled array (x,y,w,h), that I later passed back to the ESPHome to be plotted. Unfortunately, on one of the last HA updates, it stopped working and I need to find some time to fix it... Since it broke, I am just plotting the measured data with the standard points, which is not that nice, but does the job...

I will close this issue now, but for further questions don't hesitate to write me by email (jon.garcia.aguado@gmail.com) or IG (@JGAguado), I may answer faster.

Best regards and thanks for the support!

Jon

Closed 2024-01-09.

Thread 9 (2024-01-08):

ADC measurement resolution

jibrilsharafi, 2024-01-08:
Hi,

I see that the board has no external ADC or energy metering IC, which means all the (current) waveform sampling will be done on the ESP32. Isn't this non-recommended since the ADC has a lot of noise, especially in the mV region (which translates into 100s of mA and 10s of W)?

Have you taken this into account in your board design?

JGAguado, 2024-01-08:
Hi @jibrilsharafi ,

Yes, you are right, The reading is done through the internal ESP32's ADC.

This doesn't necessarily mean that has a lot of noise, since it has a 12-bit resolution and the RMS can be read in a range of 1.65V, we get a resolution of 0.402mV. Depending on the CT clamp ratio you choose, you will be able to read the current with more or less quality.
On the other hand, by using ESPHome, the [CT Clamp component](https://esphome.io/components/sensor/ct_clamp.html) computes the RMS directly, so this helps filtering undesired noise (I think around 900 samples/second).
I'm aware it's not a completely noise-proof design, but so far does a good job at a reasonable cost: for monitoring, in a non-invasive way, my home's apparent power is more than enough.

Best regards!

Closed 2024-01-08.

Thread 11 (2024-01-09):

Suitable for 3 phase?

eina84, 2024-01-09:
I just purchased one of your units on Elecrow today to replace my Neurio unit which is no longer supported & appears to have stopped working.
Is the Smart Powermeter suitable for 3 phase? My condo uses 3 phase.
Also, I ordered the pack with 6 CT Clamps - can I use 3 of them to measure the 3 phase input & then the other 3 to maybe measure specific current draws of 3 big items like my air conditioners?
(sorry if this isn't the right place to ask - I couldn't find another site with discussion area)

JGAguado, 2024-01-09:
Dear @eina84,

Yes, my apartment also uses triphasic. I am monitoring each one of the phases and so far works fine for me, and yes, with the other 3 clamps you should have no problems monitoring other current lines.
By monitoring each of the phases I compute on ESPHome the total apparent power this way:

```
 - platform: template
    id: current_power
    name: "Measured Power"
    lambda: return (id(Probe_1).state + id(Probe_2).state + id(Probe_3).state) * 230.0 / 1000; #Apparent power = Current * Voltage
    unit_of_measurement: 'kW'
    update_interval: 5s
```

This is a pic of the first version of the Smart Powermeter, but the concept is the same:
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

I will close this issue now, but for further questions don't hesitate to write me by email ([jon.garcia.aguado@gmail.com](mailto:jon.garcia.aguado@gmail.com)) or IG ([@JGAguado](https://www.instagram.com/JGaguado/)), I may answer faster.

Best regards and thanks for the support!

Jon

Closed 2024-01-09.

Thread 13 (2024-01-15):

Documentation - Assembly - Typo

mdframe, 2024-01-15:
Jon,

I found a typo in the documentation detailing the ESPHome folder structure:

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

I am working through your code to verify what is working from a user stand point.  I am also having a really difficult time finding the correct webfont file and believe this is causing me errors with the  following line:

 it.printf(x_head, y_head, id(font_icon), TextAlign::TOP_LEFT, wifi_icon_map[4].c_str());

ESPHome compiler is stating no wifi_icon_map exists, here is the error:

<unicode string>: In lambda function:
<unicode string>:269:71: error: 'wifi_icon_map' was not declared in this scope
<unicode string>:269:71: note: suggested alternative: 'wifisignal'
<unicode string>:272:71: error: 'wifi_icon_map' was not declared in this scope
<unicode string>:272:71: note: suggested alternative: 'wifisignal'
<unicode string>:275:71: error: 'wifi_icon_map' was not declared in this scope
<unicode string>:275:71: note: suggested alternative: 'wifisignal'
<unicode string>:278:71: error: 'wifi_icon_map' was not declared in this scope
<unicode string>:278:71: note: suggested alternative: 'wifisignal'
<unicode string>:281:71: error: 'wifi_icon_map' was not declared in this scope
<unicode string>:281:71: note: suggested alternative: 'wifisignal'

Again, I think this is related to the ttf file I am trying to use since I can't find the defined one in the code.  This is the only item I have an error on at this point.   Just working through the YAML prior to receiving the hardware.  I will make sure this works locally before making recommendations or changing your code as it sits right now.

Thank you,

Matt

JGAguado, 2024-01-15:
Matt,

Thanks a lot for opening the issue, it makes me really happy that at least someone read the docs hahaha. The tree typo has been corrected and I added a downloadable MDI .ttf like the one I use.

Can I close the issue or there is something else not compiling?

Best regards!

Jon

mdframe, 2024-01-15:
Thanks Jon, I'm good at this point until I get hardware in hand!  ;)

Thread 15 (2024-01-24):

New Device is DOA

mdframe, 2024-01-24:
Jean,

I received my new device today, added the power connectors and the E-Paper per instructions.  I DID NOT apply any external power.  Only using 5 different USB-C cords and two different computers I get nothing.  No connection no sign of life.  What can I check on this board for valid power and connection with the USB-C?

Thanks,

Matt

Brockhold, 2024-01-24:
Hey, I actually thought the same thing happened to me today, [but it turns out I didn't read the manual](https://smart-powermeter.readthedocs.io/en/latest/programming.html) - to show up as a USB serial device for loading firmware, after connecting the USB cable you have to hold down the FLASH button and then press the RESET button.

mdframe, 2024-01-24:
Ben,

Thank you, I've read this document several times and not sure how I missed that!  I will try this one I get home.

Appreciate the help!

Matt

JGAguado, 2024-01-24:
Thanks for answering @Brockhold ! Since it is a recurrent issue, I will emphasize it on the [FAQs](https://smart-powermeter.readthedocs.io/en/latest/faq.html)

I will close now the topic, feel free to reopen it if it didn't work!

Best regards!

Jon

Closed 2024-01-24.

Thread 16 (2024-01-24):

Measurements with `SCT-013-000` and the built-in 22R resistor seem close to identical

roobre, 2024-01-24:
Hi there!

Yesterday I finished assembling my smart power meter but I'm struggling to get it to measure reliably. Trying to go through the calibration step, the device does not seem to be able to discern no current (0A) from 2.1A as measured by an external ammeter (which also matches the expected draw for the load I connected).

The YAML I'm using is as follows:
```
sensor:
  - platform: adc
    pin: GPIO1
    id: Input_1
    attenuation: 11db
    update_interval: 1s
# ...
  - platform: ct_clamp
    name: Probe 1
    id: Probe_1
    sensor: Input_1
    sample_duration: 200ms
    update_interval: 1s
    # filters:
    #   - calibrate_linear:
    #       - 0 -> 0
    #       - 0.042 -> 2.72
# ...
```

Notice the filter section is commented out for calibration. Looking at the logs for lines like:

```
[22:55:16][D][sensor:094]: 'Probe 1': Sending state 0.00176 A with 2 decimals of accuracy
```

I collected ~20 of those lines for a 0A and a 2.1A load and crunched some numbers on a spreadsheet. From that, I got that:
- A 0A load reported an average of `0.001685` with an standard deviation of `0.00028`
- A 2.1A load reported an average of `0.001727` with an standard deviation of `0.00026`

What I understand from these numbers is that measurements of 0W (0A) and ~500W (~2A) are within standard deviation from one another, making them hardly distinguishable.

I wonder if this is expected, or if I'm doing something wrong. I'm fine hacking the meter and replacing the 22R resistors with something higher, but I would like to double-check with you to see if what I'm seeing is the expected behavior, or if on the contrary I'm doing something wrong.

[measurements.ods](https://github.com/JGAguado/Smart_Powermeter/files/14037611/measurements.ods)

roobre, 2024-01-24:
Figured this out. The adc was reading noise because, at least on my unit, it doesn't seem like you should plug the jacks all the way into the receptacles. If you do (like I did), then they don't seem to make proper contact. By pulling them out about ~1mm from the point where they would bottom out, I now get sensical readings from the ADC: `0.021 +/- 0.0002` for ~2A, and `0.042 +/- 0.0004` for ~4A.

JGAguado, 2024-01-24:
Hi @roobre,

Sorry for not having answered before. Good to know that you fixed it! I will add this issue to the [FAQ](https://smart-powermeter.readthedocs.io/en/latest/faq.html)  section on the docs if you don't mind 😃

All best

Jon

PS: Qué bien ver un usuario español apoyando el proyecto 😄

Closed 2024-01-24.

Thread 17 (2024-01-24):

Failed to Initialize

mdframe, 2024-01-24:
After pressing the flash button and reboot button to get the comm connected, when I try to install a package all I get is "Failed to initialize. Try resetting your device or holding the BOOT button while selecting your serial port until it starts preparing the installation."

I have tried different button sequences and holding buttons down but it always has the same error message.  Funning thing is through all this I can see the USB-C stay connected.

mdframe, 2024-01-24:
Requires multiple pushed between flash and reboot while trying to install.

Saentist, 2024-02-06:
> Requires multiple pushed between flash and reboot while trying to install.

Can you describe more detailed, I have same problem.

Closed 2024-01-24.

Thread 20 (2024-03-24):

Resistor replacement

JGAguado, 2024-03-24:
Replace R3,6,9,12,15 10kOhm with 15kOhm

JGAguado, 2024-04-19:
645c45ff3363b090e0412a4e9a0f5d229b200708

Closed 2024-04-19.

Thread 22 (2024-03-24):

Jack connectors

JGAguado, 2024-03-24:
Replace jack connectors to:
* Avoid the 1mm gap
* Mechanically reinforcement.
* T&S instead of RRS (with solderable jumper for an optional RSS)

JGAguado, 2024-04-19:
645c45ff3363b090e0412a4e9a0f5d229b200708

Closed 2024-04-19.

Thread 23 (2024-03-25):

No wifi, No display, nothing

jedon, 2024-03-25:
I got one from Elecrow and am trying to get it running. I had a lot of issue with esphome but via CLI finally got it to make be a bin file and I flashed it using flash_download_tool_3.9.6. No matter what I do the device just seems dead. No wifi, nothing on the screen, no lights, nothing. Only reason I don't think it's totally dead is that I can put it in flash mode and flash it. I connect with serial and nothing.  I'm no stranger to microcontrollers or esp32's, I wrote FAT32 and cell modem firmware. Any help? Thanks!

jedon, 2024-03-28:
Thank you much to @JGAguado I got it working, it was nothing to do with the device itself.

Closed 2024-03-28.

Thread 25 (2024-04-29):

Watts measurements.

rowlest, 2024-04-29:
Hi got your system up and running! Very fun.
Just wondering if voltage is measured at all so the watts can be measured for each circuit accurately ?

Not just w = 230 * a

Also with your base yaml be nice if it was full fleshed out with a complete setup eg
 LED power on boot
Total kw for 6 probes not 3
Watts returned not just amps for each circuit

Also I couldn't flash via USB had to be done via serial but all working OTA/USB once flashed.

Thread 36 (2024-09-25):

Not 0 when mo power  !

vincegre, 2024-09-25:
Hi

Just bought the complete kit and I'm quite impressed by quality of the board and design but I have an annoying issue. Even without CT connected or CT connected but laying on table, ESPHome reports some small consumptions on each input ! I have around 100W measured while it should be 0.
I'm using your default code as you supply. How to fix the problem ?

Thanks

Vincèn

JGAguado, 2024-09-25:
Hi Vincèn,

Thanks for supporting the project! It can be that you may need to play around the calibration coefficients associated to each CT clamp. @lucazeta1975 opened some days ago a nice [discussion ](https://github.com/JGAguado/Smart_Powermeter/discussions/35) with some updated calibration factors, I'd recommend them to give them a try or check out the [calibration procedure from the docs ](https://smart-powermeter.readthedocs.io/en/v2r2/installation.html#calibration) 😉😉.

Let me know if this helps.

PS: I'm converting this issue to a discussion as it fits better.

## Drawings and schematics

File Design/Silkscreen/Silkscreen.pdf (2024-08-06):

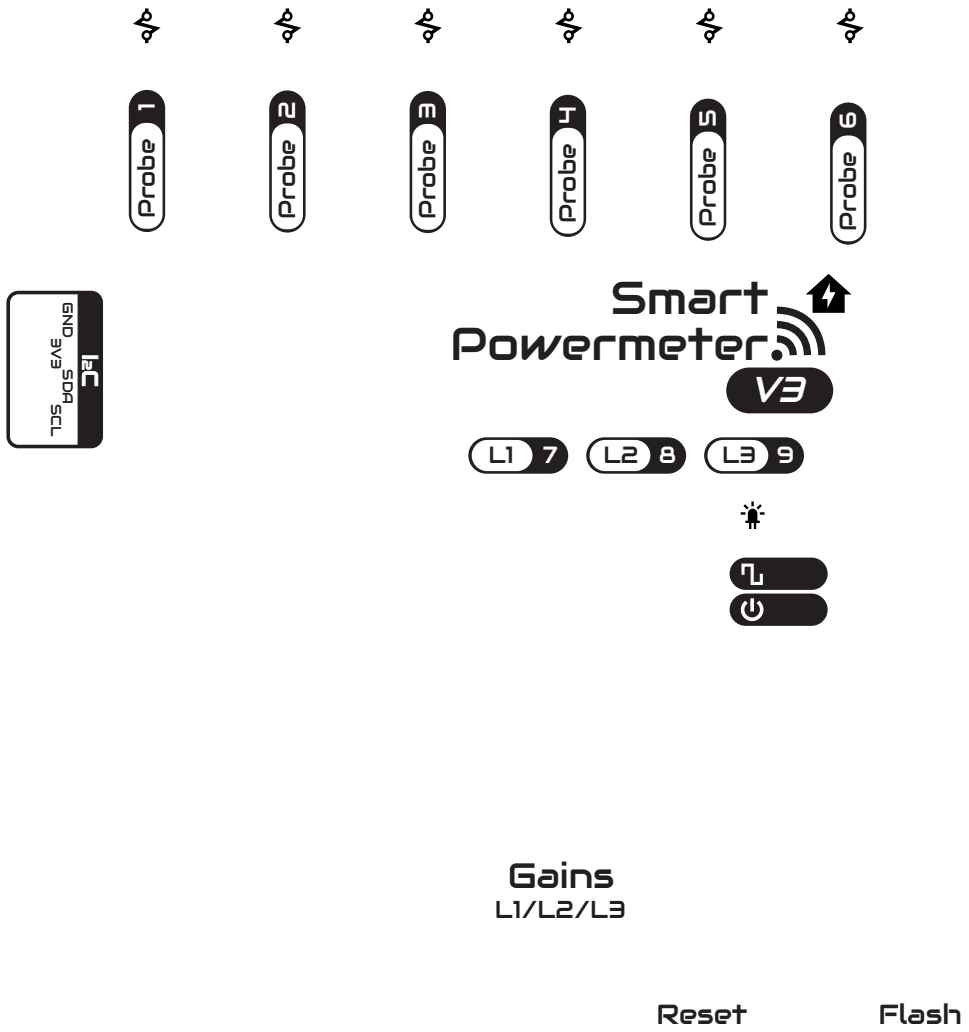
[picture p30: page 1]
Smart Powermeter V3; Probe; Reset; Gains L1/L2/L3; Flash; SCL; GND SDA

# Smart

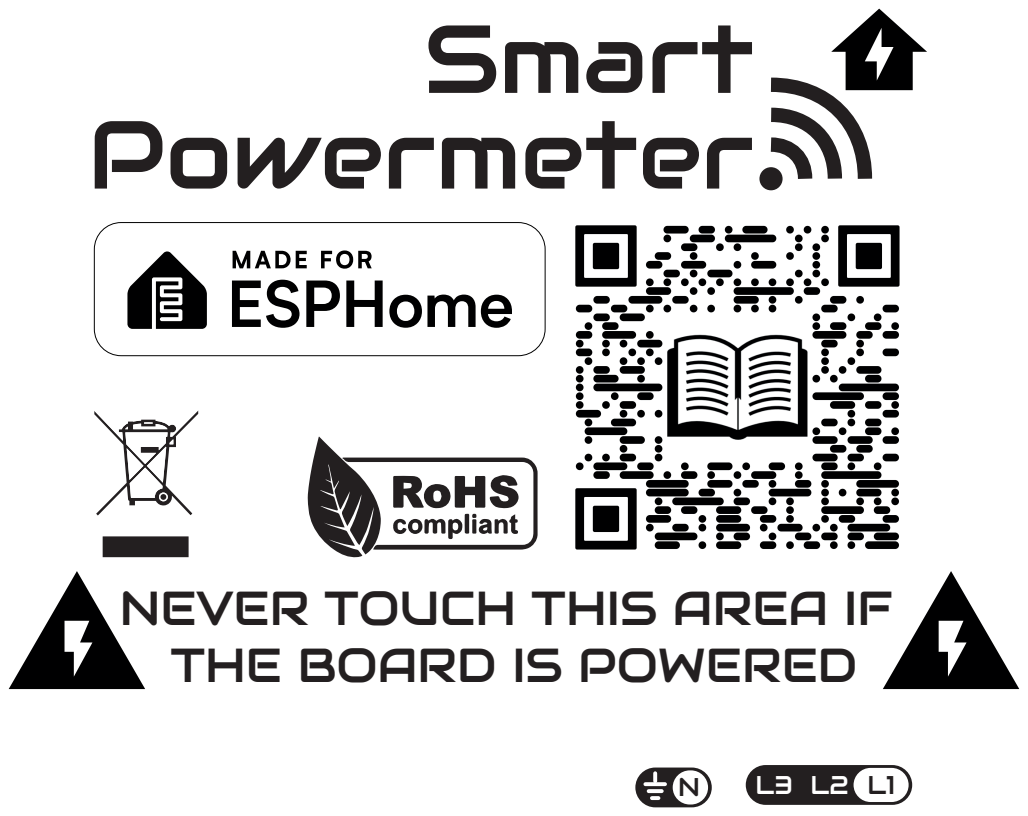
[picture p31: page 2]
Powermeter

NEVER TOUCH THIS AREA IF
THE BOARD IS POWERED

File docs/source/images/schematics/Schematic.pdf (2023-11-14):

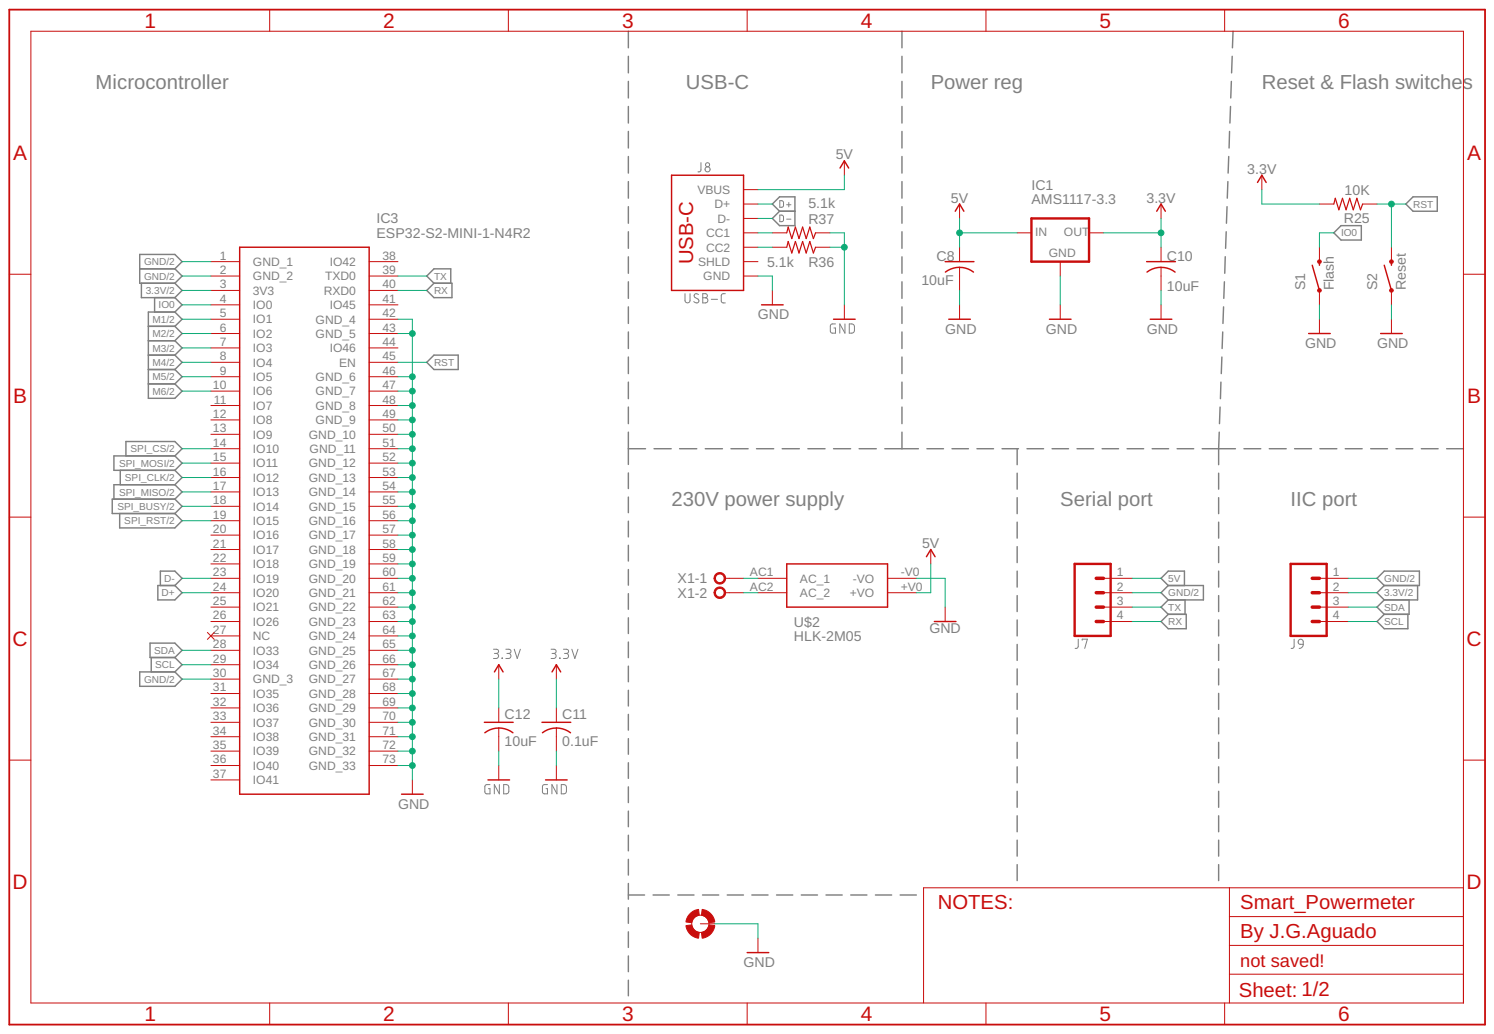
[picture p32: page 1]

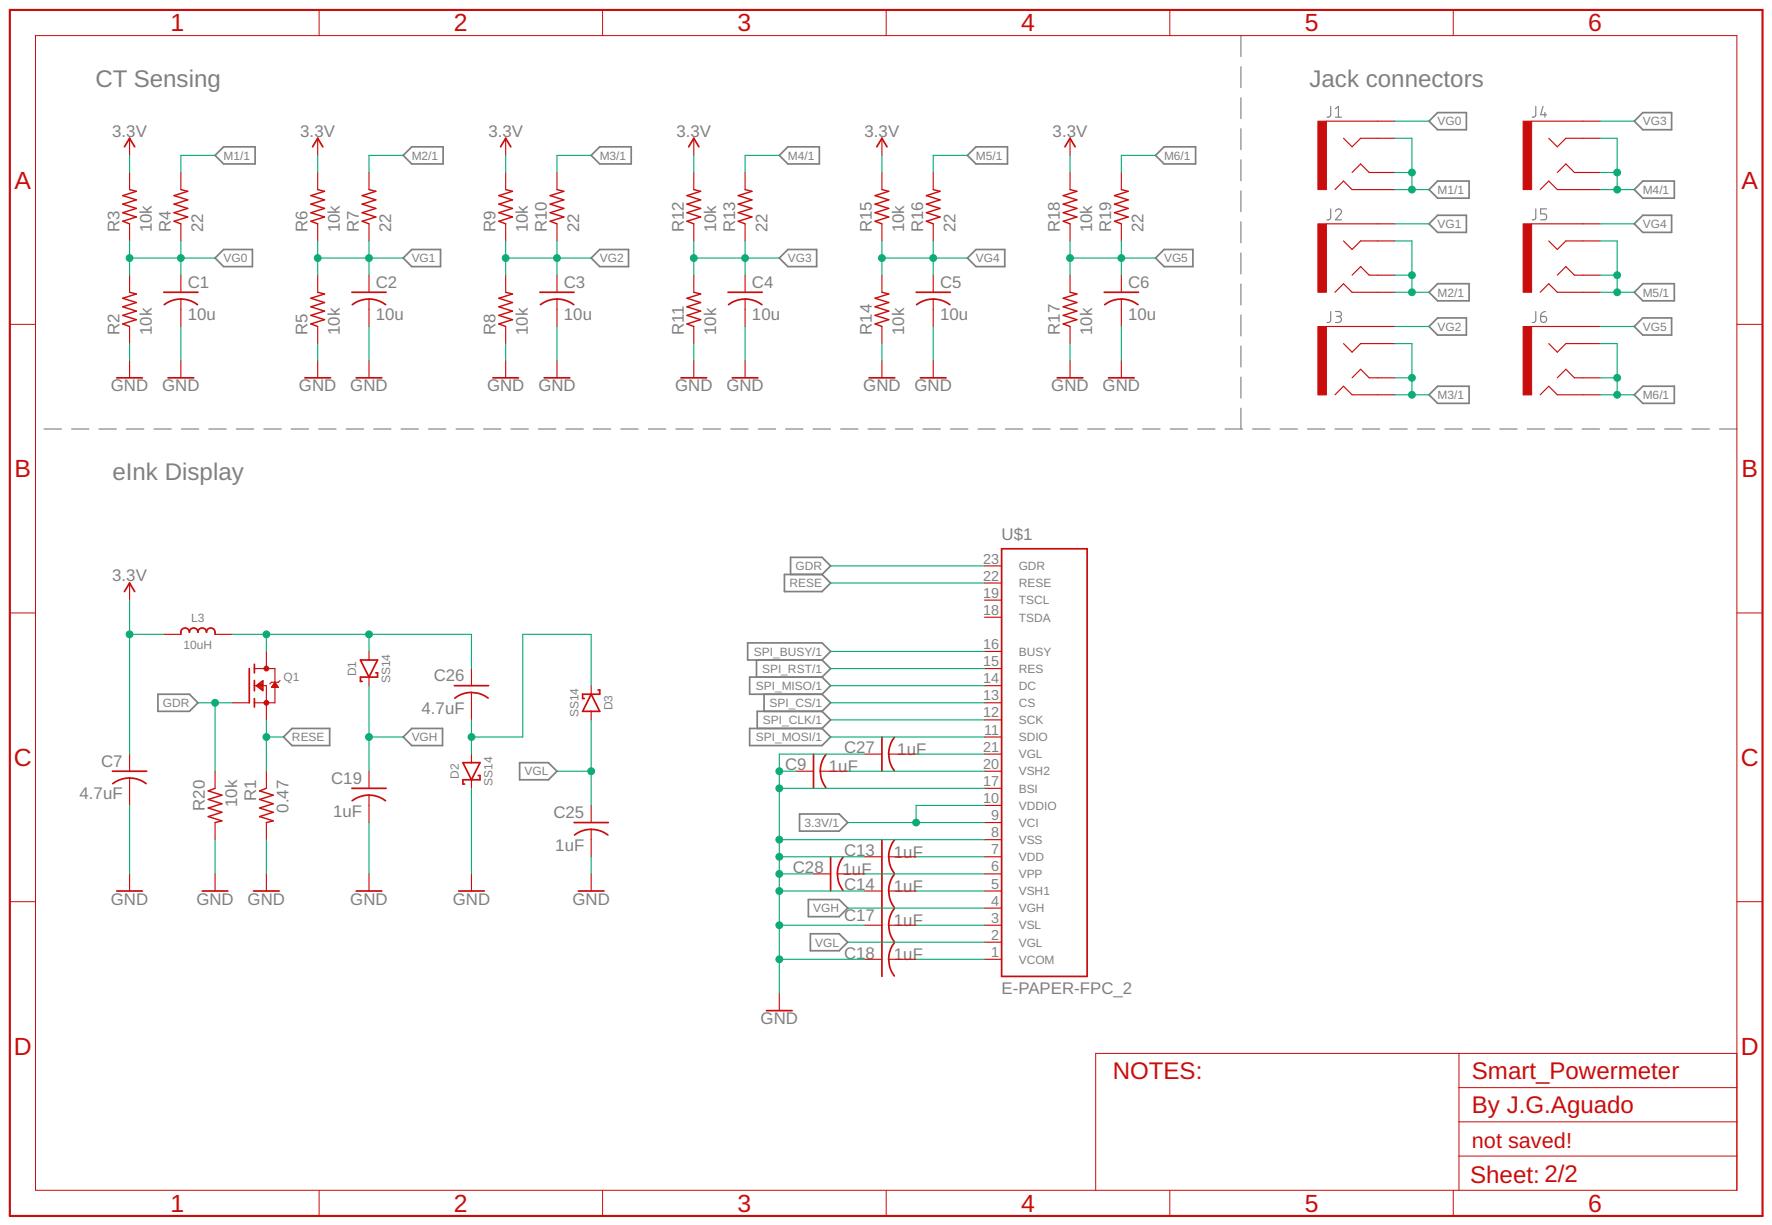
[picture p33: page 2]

3.3V/1 VGH C13 | 7 1uF

1uF | 6
C14 | 1uF 5

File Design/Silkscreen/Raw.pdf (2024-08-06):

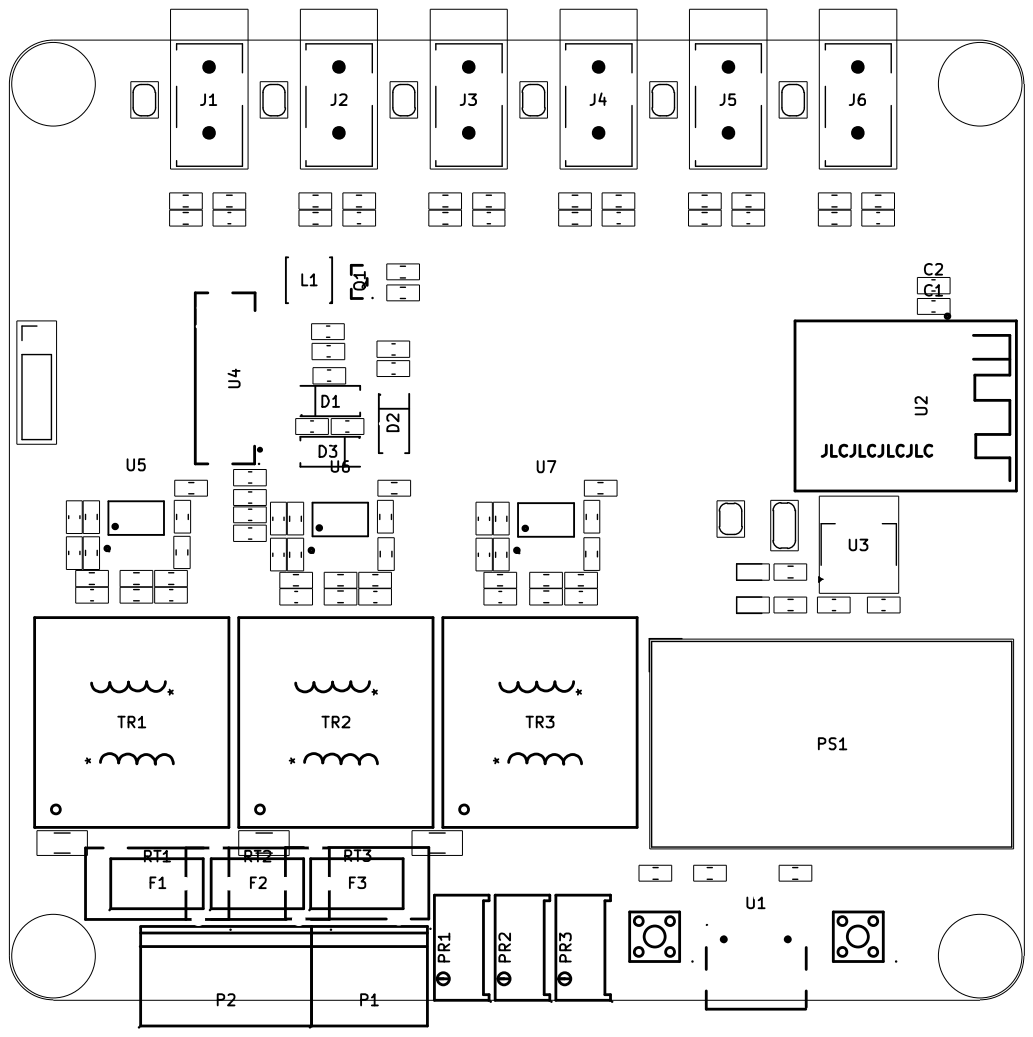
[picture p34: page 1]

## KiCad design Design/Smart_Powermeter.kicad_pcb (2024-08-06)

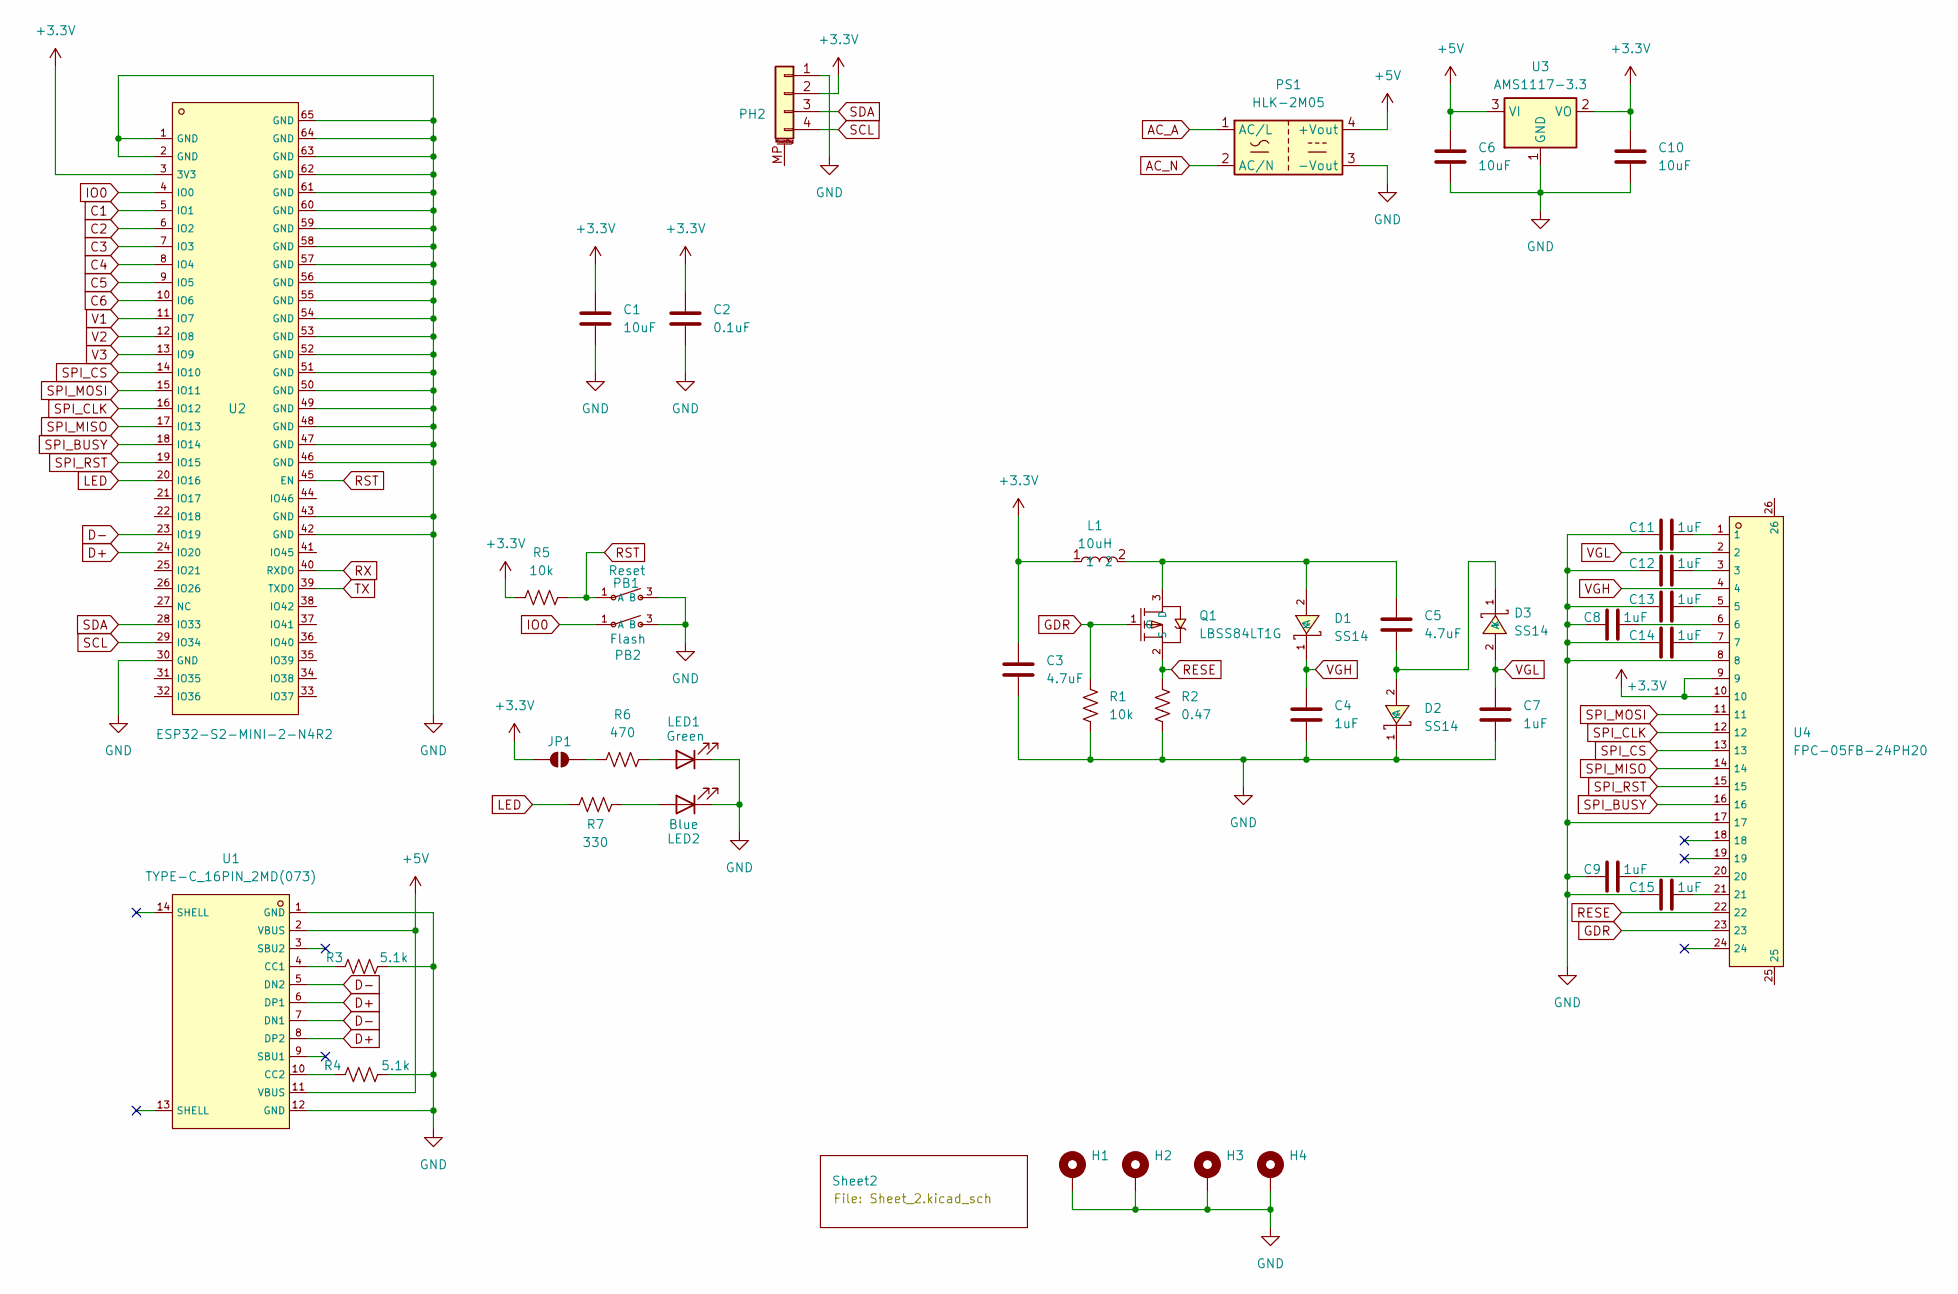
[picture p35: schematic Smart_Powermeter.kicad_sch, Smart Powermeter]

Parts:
C1, C6, C10: 10uF; C_0603_1608Metric
C2: 0.1uF; C_0603_1608Metric
C3, C5: 4.7uF; C_0603_1608Metric
C4, C7, C8, C9, C11, C12, C13, C14, C15: 1uF; C_0603_1608Metric
D1, D2, D3: SS14; SMA_L4.2-W2.6-LS5.3-RD; LCSC C2480
H1, H2, H3, H4: MountingHole_Pad; MountingHole_3.5mm_Pad_Via
JP1: SolderJumper_2_Bridged; SolderJumper-2_P1.3mm_Open_RoundedPad1.0x1.5mm
L1: 10uH; IND-SMD_L4.0-W4.0; LCSC C340393
LED1: Green; LED_0603_1608Metric
LED2: Blue; LED_0603_1608Metric
PB1: Reset; SW-SMD_4P-L4.5-W4.5-P3.00-LS6.8; LCSC C5342982
PB2: Flash; SW-SMD_4P-L4.5-W4.5-P3.00-LS6.8; LCSC C5342982
PH2: Conn_01x04_MountingPin; PinHeader_1x04_P2.54mm_Vertical
PS1: HLK-2M05; Converter_ACDC_Hi-Link_HLK-2Mxx
Q1: LBSS84LT1G; SOT-23_L2.9-W1.3-P1.90-LS2.4-BR; LCSC C8492
R1, R5: 10k; R_0603_1608Metric
R2: 0.47; R_0603_1608Metric
R3, R4: 5.1k; R_0603_1608Metric
R6: 470; R_0603_1608Metric
R7: 330; R_0603_1608Metric
U1: TYPE-C_16PIN_2MD(073); USB-C-SMD_TYPE-C-6PIN-2MD-073; LCSC C2765186
U2: ESP32-S2-MINI-2-N4R2; WIFI-SMD_ESP32-MINI-1-N4; LCSC C3013908
U3: AMS1117-3.3; SOT-223-3_TabPin2
U4: FPC-05FB-24PH20; FPC-SMD_24P-P0.50_FPC-05FB-24PH20; LCSC C2856831

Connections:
+3.3V: C1.1, C2.1, C3.1, C10.1, JP1.1 (A), L1.1, PH2.2, R5.1, U2.3 (3V3), U3.2 (VO), U4.9, U4.10; also elsewhere on the board
+5V: C6.1, PS1.4 (+Vout), U1.2 (VBUS), U1.11 (VBUS), U3.3 (VI); also elsewhere on the board
AC_A: PS1.1 (AC/L); also elsewhere on the board
AC_N: PS1.2 (AC/N); also elsewhere on the board
C1: U2.5 (IO1); also elsewhere on the board
C2: U2.6 (IO2); also elsewhere on the board
C3: U2.7 (IO3); also elsewhere on the board
C4: U2.8 (IO4); also elsewhere on the board
C5: U2.9 (IO5); also elsewhere on the board
C6: U2.10 (IO6); also elsewhere on the board
D+: U1.6 (DP1), U1.8 (DP2), U2.24 (IO20)
D-: U1.5 (DN2), U1.7 (DN1), U2.23 (IO19)
GDR: Q1.1 (G), R1.1, U4.23
GND: C1.2, C2.2, C3.2, C4.2, C6.2, C7.2, C8.1, C9.1, C10.2, C11.1, C12.1, C13.1, C14.1, C15.1, D2.1 (K), H1.1, H2.1, H3.1, H4.1, LED1.1 (K), LED2.1 (K), PB1.3 (B), PB2.3 (B), PH2.1, PS1.3 (-Vout), R1.2, R2.2, R3.2, R4.2, U1.1 (GND), U1.12 (GND), U2.1 (GND), U2.2 (GND), U2.30 (GND), U2.42 (GND), U2.43 (GND), U2.46 (GND), U2.47 (GND), U2.48 (GND), U2.49 (GND), U2.50 (GND), U2.51 (GND), U2.52 (GND), U2.53 (GND), U2.54 (GND), U2.55 (GND), U2.56 (GND), U2.57 (GND), U2.58 (GND), U2.59 (GND), U2.60 (GND), U2.61 (GND), U2.62 (GND), U2.63 (GND), U2.64 (GND), U2.65 (GND), U3.1 (GND), U4.8, U4.17; also elsewhere on the board
IO0: PB2.1 (A), U2.4 (IO0)
LED: R7.1, U2.20 (IO16)
unnamed: C8.2, U4.6
unnamed: C9.2, U4.20
unnamed: C11.2, U4.1
unnamed: C12.2, U4.3
unnamed: C13.2, U4.5
unnamed: C14.2, U4.7
unnamed: C15.2, U4.21
unnamed: C5.1, D1.2 (A), L1.2, Q1.3 (D)
unnamed: C5.2, D2.2 (A), D3.1 (K)
unnamed: JP1.2 (B), R6.1
unnamed: LED1.2 (A), R6.2
unnamed: LED2.2 (A), R7.2
unnamed: R3.1, U1.4 (CC1)
unnamed: R4.1, U1.10 (CC2)
RESE: Q1.2 (S), R2.1, U4.22
RST: PB1.1 (A), R5.2, U2.45 (EN)
RX: U2.40 (RXD0)
SCL: PH2.4, U2.29 (IO34)
SDA: PH2.3, U2.28 (IO33)
SPI_BUSY: U2.18 (IO14), U4.16
SPI_CLK: U2.16 (IO12), U4.12
SPI_CS: U2.14 (IO10), U4.13
SPI_MISO: U2.17 (IO13), U4.14
SPI_MOSI: U2.15 (IO11), U4.11
SPI_RST: U2.19 (IO15), U4.15
TX: U2.39 (TXD0)
V1: U2.11 (IO7); also elsewhere on the board
V2: U2.12 (IO8); also elsewhere on the board
V3: U2.13 (IO9); also elsewhere on the board
VGH: C4.1, D1.1 (K), U4.4
VGL: C7.1, D3.2 (A), U4.2

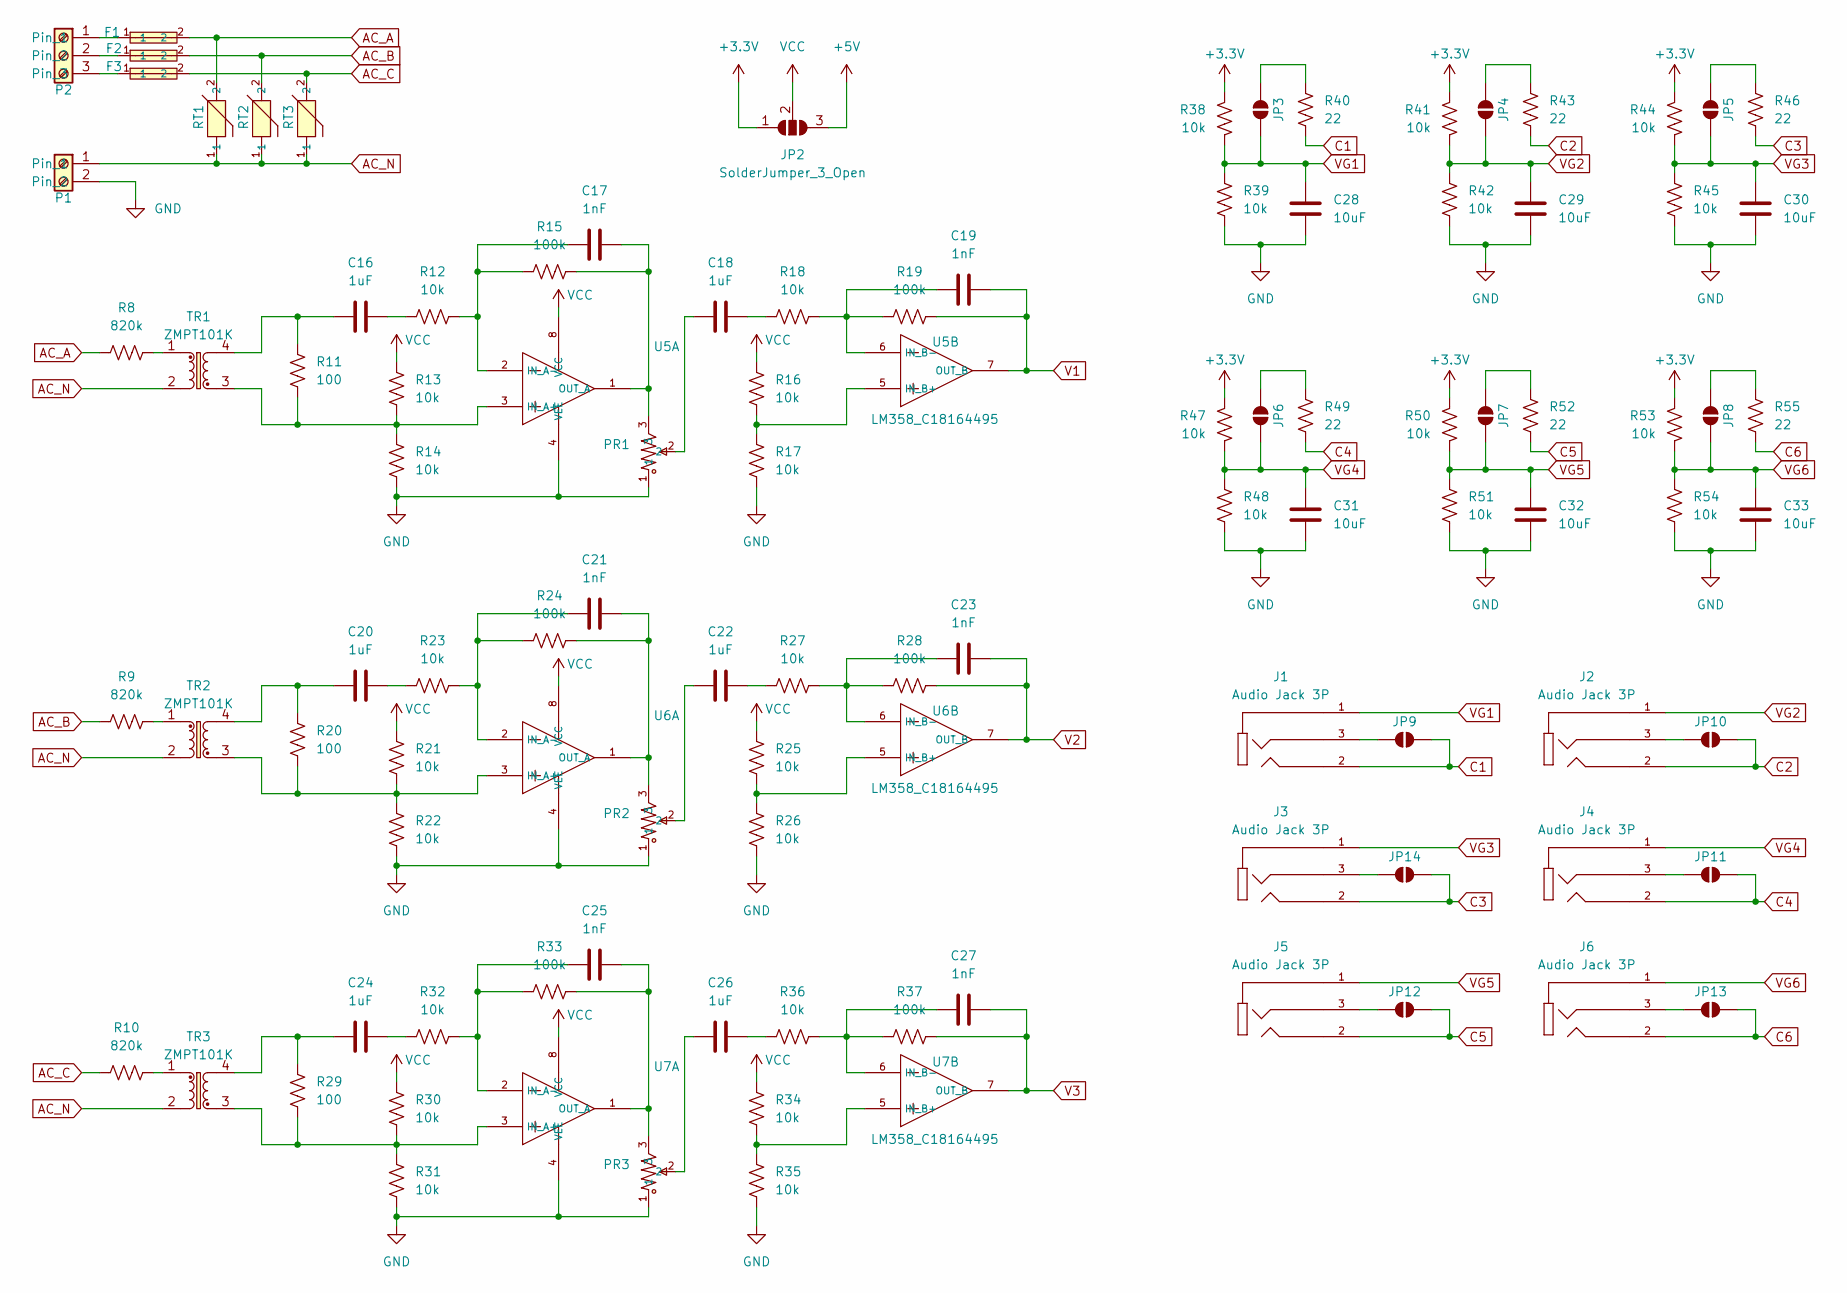
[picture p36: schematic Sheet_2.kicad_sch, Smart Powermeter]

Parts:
C16, C18, C20, C22, C24, C26: 1uF; C_0603_1608Metric
C17, C19, C21, C23, C25, C27: 1nF; C_0603_1608Metric
C28, C29, C30, C31, C32, C33: 10uF; C_0603_1608Metric
F1, F2, F3: MST1A250V; FUSE-TH_L8.4-W4.3-P5.08-D0.7; LCSC C340909
J1, J2, J3, J4, J5, J6: Audio Jack 3P; PJ-320B; PARTREV 1.05
JP2: SolderJumper_3_Open; SolderJumper-3_P1.3mm_Bridged12_RoundedPad1.0x1.5mm_NumberL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
JP3, JP4, JP5, JP6, JP7, JP8, JP9, JP10, JP11, JP12, JP13, JP14: SolderJumper_2_Bridged; SolderJumper-2_P1.3mm_Open_RoundedPad1.0x1.5mm
P1: WJ300V-5_0-2P; CONN-TH_2P-P5.00_WJ300V-5.00-2P; LCSC C8385
P2: WJ300V-5_0-3P; CONN-TH_3P-P5.00_WJ300V-5.00-3P; LCSC C8467
PR1, PR2, PR3: 3296W-1-103; RES-ADJ-TH_3P-L10.0-W10.0-P2.50-L; LCSC C118954
R8, R9, R10: 820k; R_1206_3216Metric
R11, R20, R29: 100; R_0603_1608Metric
R12, R13, R14, R16, R17, R18, R21, R22, R23, R25, R26, R27, R30, R31, R32, R34, R35, R36, R38, R39, R41, R42, R44, R45, R47, R48, R50, R51, R53, R54: 10k; R_0603_1608Metric
R15, R19, R24, R28, R33, R37: 100k; R_0603_1608Metric
R40, R43, R46, R49, R52, R55: 22; R_0603_1608Metric
RT1, RT2, RT3: 10D561K_C338652; RES-TH_L13.0-W6.7-P7.50-D0.7-S5.30; LCSC C338652
TR1, TR2, TR3: ZMPT101K; XFMR-TH_ZMPT101K; LCSC C3034722
U5, U6, U7: LM358_C18164495; SOIC-8_L4.9-W3.9-P1.27-LS6.0-BL; LCSC C18164495

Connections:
+3.3V: JP2.1 (A), R38.2, R41.2, R44.2, R47.2, R50.2, R53.2; also elsewhere on the board
+5V: JP2.3 (B); also elsewhere on the board
AC_A: F1.2, R8.1, RT1.2; also elsewhere on the board
AC_B: F2.2, R9.1, RT2.2
AC_C: F3.2, R10.1, RT3.2
AC_N: P1.1, RT1.1, RT2.1, RT3.1, TR1.2, TR2.2, TR3.2; also elsewhere on the board
C1: J1.2, JP9.1 (A), R40.1; also elsewhere on the board
C2: J2.2, JP10.1 (A), R43.1; also elsewhere on the board
C3: J3.2, JP14.1 (A), R46.1; also elsewhere on the board
C4: J4.2, JP11.1 (A), R49.1; also elsewhere on the board
C5: J5.2, JP12.1 (A), R52.1; also elsewhere on the board
C6: J6.2, JP13.1 (A), R55.1; also elsewhere on the board
GND: C28.2, C29.2, C30.2, C31.2, C32.2, C33.2, P1.2, PR1.1, PR2.1, PR3.1, R14.1, R17.1, R22.1, R26.1, R31.1, R35.1, R39.1, R42.1, R45.1, R48.1, R51.1, R54.1, U5.4 (VEE), U6.4 (VEE), U7.4 (VEE); also elsewhere on the board
unnamed: C16.1, R12.1
unnamed: C16.2, R11.1, TR1.4
unnamed: C18.1, R18.1
unnamed: C18.2, PR1.2
unnamed: C20.1, R23.1
unnamed: C20.2, R20.1, TR2.4
unnamed: C22.1, R27.1
unnamed: C22.2, PR2.2
unnamed: C24.1, R32.1
unnamed: C24.2, R29.1, TR3.4
unnamed: C26.1, R36.1
unnamed: C26.2, PR3.2
unnamed: JP3.2 (B), R40.2
unnamed: JP4.2 (B), R43.2
unnamed: JP5.2 (B), R46.2
unnamed: JP6.2 (B), R49.2
unnamed: JP7.2 (B), R52.2
unnamed: JP8.2 (B), R55.2
unnamed: J1.3, JP9.2 (B)
unnamed: J2.3, JP10.2 (B)
unnamed: J4.3, JP11.2 (B)
unnamed: J5.3, JP12.2 (B)
unnamed: J6.3, JP13.2 (B)
unnamed: J3.3, JP14.2 (B)
unnamed: F1.1, P2.1
unnamed: F2.1, P2.2
unnamed: F3.1, P2.3
unnamed: R8.2, TR1.1
unnamed: R9.2, TR2.1
unnamed: R10.2, TR3.1
unnamed: R11.2, R13.1, R14.2, TR1.3, U5.3 (IN_A+)
unnamed: C17.2, R12.2, R15.1, U5.2 (IN_A-)
unnamed: C17.1, PR1.3, R15.2, U5.1 (OUT_A)
unnamed: R16.1, R17.2, U5.5 (IN_B+)
unnamed: C19.2, R18.2, R19.1, U5.6 (IN_B-)
unnamed: R20.2, R21.1, R22.2, TR2.3, U6.3 (IN_A+)
unnamed: C21.2, R23.2, R24.1, U6.2 (IN_A-)
unnamed: C21.1, PR2.3, R24.2, U6.1 (OUT_A)
unnamed: R25.1, R26.2, U6.5 (IN_B+)
unnamed: C23.2, R27.2, R28.1, U6.6 (IN_B-)
unnamed: R29.2, R30.1, R31.2, TR3.3, U7.3 (IN_A+)
unnamed: C25.2, R32.2, R33.1, U7.2 (IN_A-)
unnamed: C25.1, PR3.3, R33.2, U7.1 (OUT_A)
unnamed: R34.1, R35.2, U7.5 (IN_B+)
unnamed: C27.2, R36.2, R37.1, U7.6 (IN_B-)
V1: C19.1, R19.2, U5.7 (OUT_B); also elsewhere on the board
V2: C23.1, R28.2, U6.7 (OUT_B); also elsewhere on the board
V3: C27.1, R37.2, U7.7 (OUT_B); also elsewhere on the board
VCC: JP2.2 (C), R13.2, R16.2, R21.2, R25.2, R30.2, R34.2, U5.8 (VCC), U6.8 (VCC), U7.8 (VCC)
VG1: C28.1, J1.1, JP3.1 (A), R38.1, R39.2
VG2: C29.1, J2.1, JP4.1 (A), R41.1, R42.2
VG3: C30.1, J3.1, JP5.1 (A), R44.1, R45.2
VG4: C31.1, J4.1, JP6.1 (A), R47.1, R48.2
VG5: C32.1, J5.1, JP7.1 (A), R50.1, R51.2
VG6: C33.1, J6.1, JP8.1 (A), R53.1, R54.2

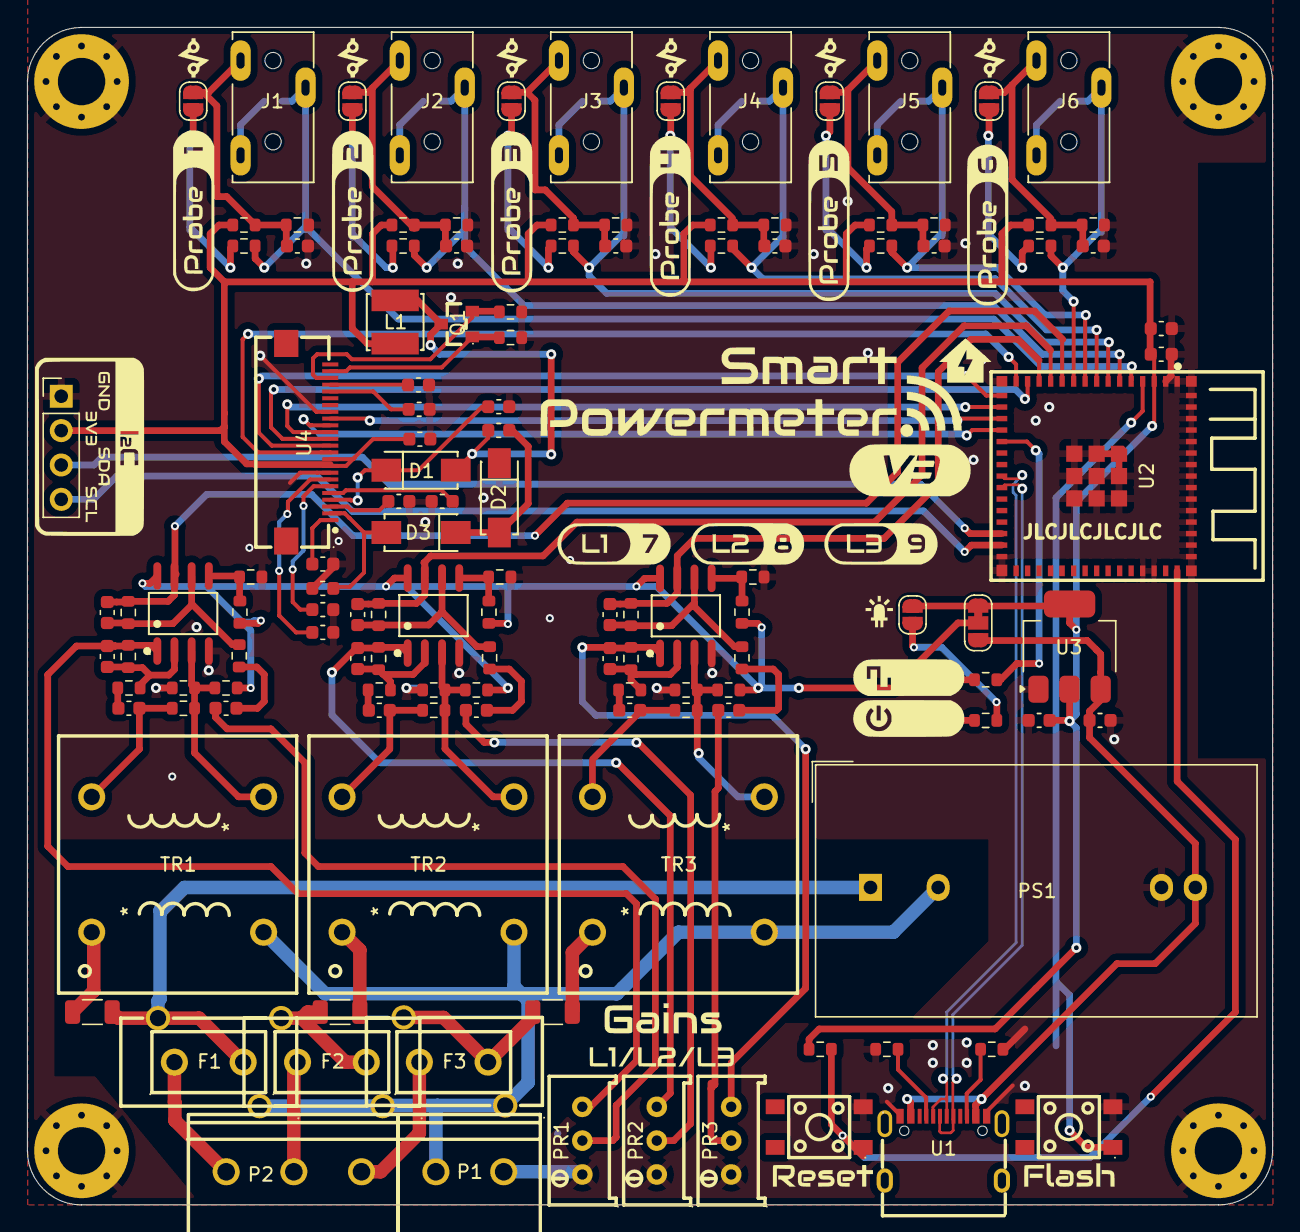
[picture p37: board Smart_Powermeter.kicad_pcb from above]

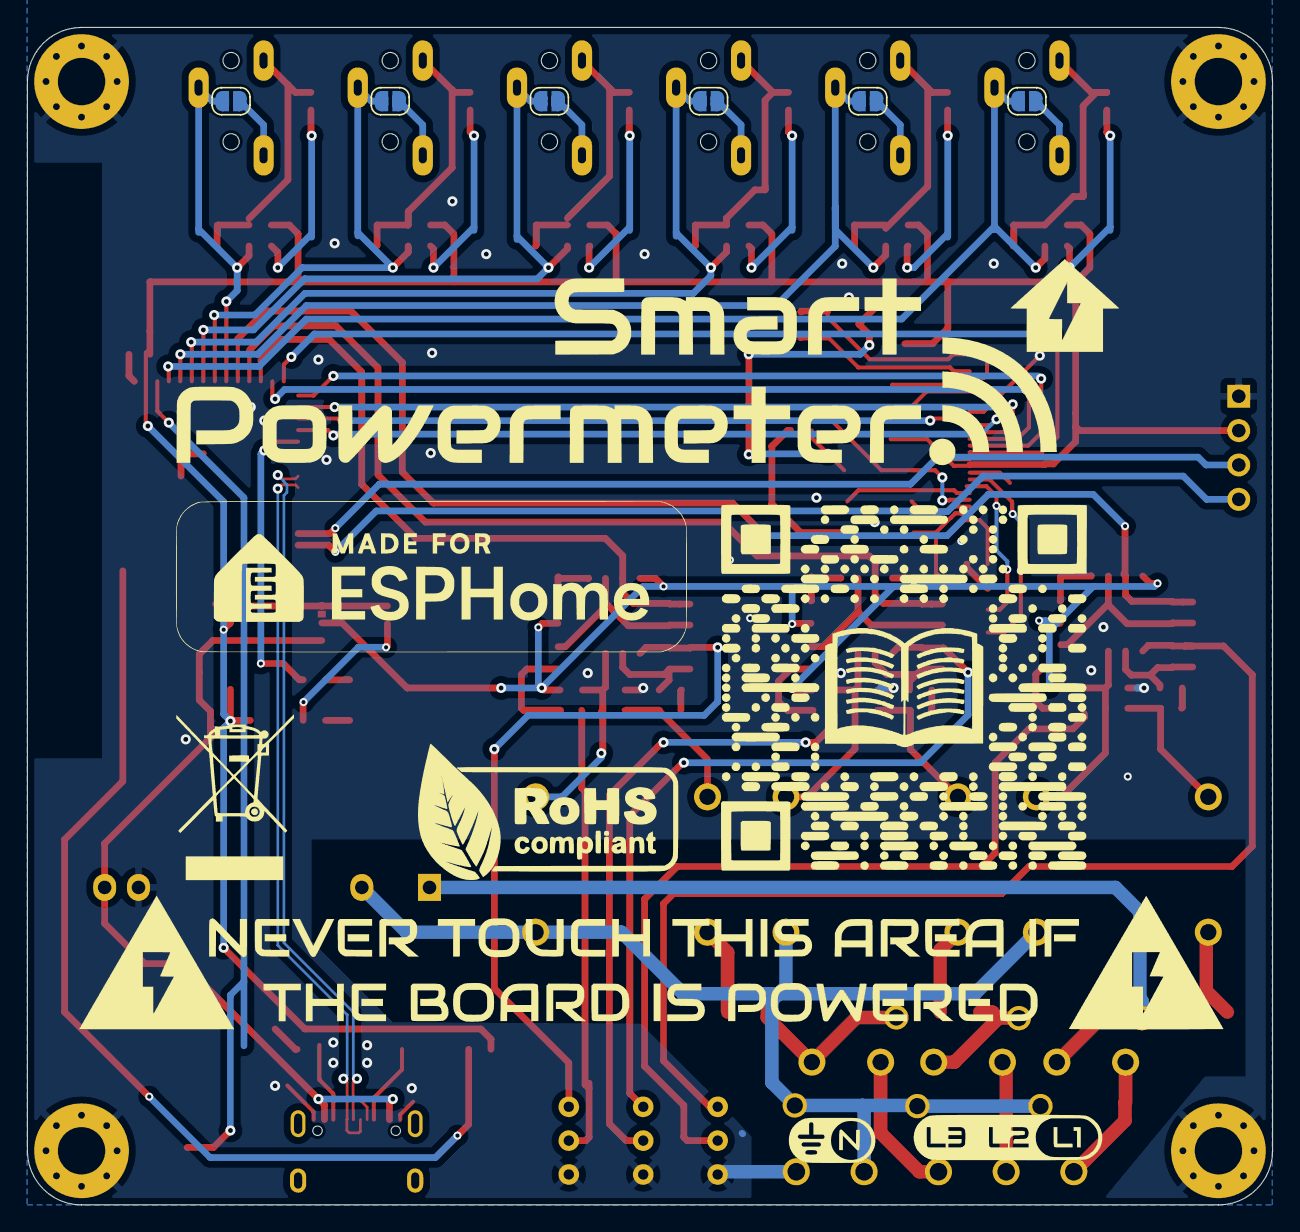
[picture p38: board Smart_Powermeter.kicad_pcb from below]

Board: 2 copper layers, 92.0 x 87.0 mm, 144 parts (6 on the bottom side), 99 nets.

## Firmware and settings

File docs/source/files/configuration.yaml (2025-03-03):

substitutions:
  device_name: "smart-powermeter"
  friendly_name: "Smart Powermeter"
  project_name: "smart.powermeter"
  project_version: "2.0"
  ap_ssid: "Smart-Powermeter"
  ap_pwd: "smartpowermeter"

esphome:
  name: "${device_name}"
  name_add_mac_suffix: true
  project:
    name: "${project_name}"
    version: "${project_version}"

esp32:
  board: esp32-s2-saola-1
  framework:
    type: arduino

# Enable logging
logger:

# Enable Home Assistant API
api:

# Enable Over The Air updates
ota:
  platform: esphome

#Public location of this yaml file
dashboard_import:
  package_import_url: github://JGAguado/Smart_Powermeter/docs/source/files/configuration.yaml@V2R2
  import_full_config: true

# Enable fallback hotspot (captive portal) in case wifi connection fails
captive_portal:


improv_serial:

wifi:
  ap:
    ssid: "${ap_ssid}"
    password: "${ap_pwd}"

time:
  - platform: homeassistant
    id: esptime

sensor:    
  - platform: adc
    pin: GPIO1
    id: Input_1
    attenuation: 12db
    update_interval: 1s
    
  - platform: adc
    pin: GPIO2
    id: Input_2
    attenuation: 12db
    update_interval: 1s
    
  - platform: adc
    pin: GPIO3
    id: Input_3
    attenuation: 12db
    update_interval: 1s
    
  - platform: adc
    pin: GPIO4
    id: Input_4
    attenuation: 12db
    update_interval: 1s
    
  - platform: adc
    pin: GPIO5
    id: Input_5
    attenuation: 12db
    update_interval: 1s
    
  - platform: adc
    pin: GPIO6
    id: Input_6
    attenuation: 12db
    update_interval: 1s

  - platform: ct_clamp
    sensor: Input_1
    id: Probe_1
    name: "Probe 1"
    sample_duration: 200ms
    update_interval: 1s
    filters:
      - calibrate_linear:
          - 0 -> 0
          - 0.042 -> 2.72
    
  - platform: ct_clamp
    sensor: Input_2
    name: "Probe 2"
    id: Probe_2
    sample_duration: 200ms
    update_interval: 1s
    filters:
      - calibrate_linear:
          - 0 -> 0
          - 0.033 -> 1.07
    
  - platform: ct_clamp
    sensor: Input_3
    name: "Probe 3"
    id: Probe_3
    sample_duration: 200ms
    update_interval: 1s
    filters:
      - calibrate_linear:
          - 0 -> 0
          - 0.022 -> 0.66
    
  - platform: ct_clamp
    sensor: Input_4
    name: "Probe 4"
    id: Probe_4
    sample_duration: 200ms
    update_interval: 1s
    filters:
      - calibrate_linear:
          - 0 -> 0
          - 0.022 -> 0.66

  - platform: ct_clamp
    sensor: Input_5
    name: "Probe 5"
    id: Probe_5
    sample_duration: 200ms
    update_interval: 1s
    filters:
      - calibrate_linear:
          - 0 -> 0
          - 0.022 -> 0.66

  - platform: ct_clamp
    sensor: Input_6
    name: "Probe 6"
    id: Probe_6
    sample_duration: 200ms
    update_interval: 1s
    filters:
      - calibrate_linear:
          - 0 -> 0
          - 0.022 -> 0.66
          
  - platform: total_daily_energy
    name: "Total Daily Power"
    power_id: current_power
    id: daily_power

  - platform: template
    id: current_power
    name: "Measured Power"
    lambda: return (id(Probe_1).state + id(Probe_2).state + id(Probe_3).state) * 230.0 / 1000; #Power = Current * Voltage 
    unit_of_measurement: 'kW'
    update_interval: 5s

  # WiFi Signal     
  - platform: wifi_signal
    name: "WiFi Signal Sensor"
    id: wifisignal
    update_interval: 20s

  # Homeassistant data
  - platform: homeassistant
    id: cost
    entity_id: sensor.smart_powermeter_total_daily_power_cost

font:
  - file: "gfonts://Audiowide"
    id: font_header
    size: 15
  - file: "gfonts://Audiowide"
    id: font_gauge
    size: 15
  - file: "gfonts://Audiowide"
    id: font_text
    size: 15
  - file: 'gfonts://Material+Symbols+Outlined'
    id: font_icon
    size: 18
    glyphs:
      - "\U0000f0b0" # wifi-strength-0
      - "\U0000ebe4" # wifi-strength-1
      - "\U0000ebd6" # wifi-strength-2
      - "\U0000ebe1" # wifi-strength-3
      - "\U0000e1d8" # wifi-strength-4

spi:
  clk_pin: GPIO12
  mosi_pin: GPIO11  # Works on the e-paper

image:
  - file: https://smart-powermeter.readthedocs.io/en/v2r2/_images/Gauge.png
    id: gauge
    type: binary

  - file: https://smart-powermeter.readthedocs.io/en/v2r2/_images/Gauge_1.png
    id: gauge_1 
    type: binary

  - file: mdi:home-lightning-bolt
    id: power
    type: grayscale
    resize: 18x18
    
  - file: mdi:cash-multiple
    id: cash
    type: grayscale
    resize: 18x18

  - file: mdi:currency-eur
    id: euro
    type: grayscale
    resize: 18x18

  - file: mdi:lightning-bolt
    id: bolt
    type: grayscale
    resize: 22x22
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

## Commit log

2022-04-13 Added silkscreen design
2022-04-13 Added design files
    [Smart_Powermeter.brd, Smart_Powermeter.sch]
2022-04-13 Updated silkscreen files
2022-04-13 Updated design files fixing Release 1 bugs
    [Smart_Powermeter.brd, Smart_Powermeter.sch]
2022-05-29 Resize dimensions to fit in the 92x87 enclosure
    [Smart_Powermeter.brd, Smart_Powermeter.sch]
2023-04-19 Added design files of V2
    [Smart_Powermeter.brd, Smart_Powermeter.sch]
2023-11-14 Updated design files
    [Smart_Powermeter.brd, Smart_Powermeter.sch]
2024-01-31 fixed the missing "0" on the docs
    [configuration.yaml]
2024-03-19 First draft for the Pro version
    [Smart_Powermeter.brd, Smart_Powermeter.sch]
2024-06-12 Smart Powermeter Pro with V/I measurements directly on the ESP32-S2
    [Smart_Powermeter.brd, Smart_Powermeter.sch]
2024-07-10 Former Eagle files moved to Eagle
    [Smart_Powermeter.brd, Smart_Powermeter.sch]
2024-07-10 Added KiCad files with a first draft for the V3R1
    [Sheet_1.kicad_sch, Sheet_2.kicad_sch, Smart_Powermeter.kicad_pcb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]
2024-08-01 First draft V3R1
    [Smart_Powermeter.kicad_pcb]
2024-08-06 Cleared path around antenna and removed Serial port
    [Smart_Powermeter.kicad_pcb, Smart_Powermeter.kicad_sch]
